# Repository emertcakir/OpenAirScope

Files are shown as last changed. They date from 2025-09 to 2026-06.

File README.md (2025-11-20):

EMC
------
# OpenAirScope 🌍💨

**OpenAirScope** is an open-source hardware and software project designed for advanced environmental monitoring and air quality measurement. It is based on the STM32H743 and ESP32-C3, supports LoRaWAN, and is equipped with a wide range of up-to-date sensors and display options.

### PCB 3D
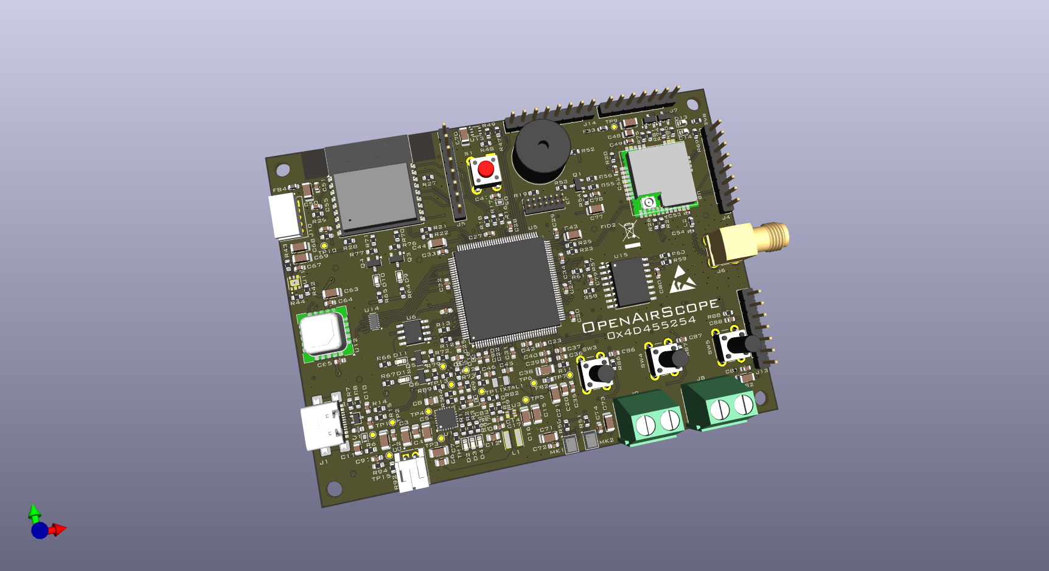
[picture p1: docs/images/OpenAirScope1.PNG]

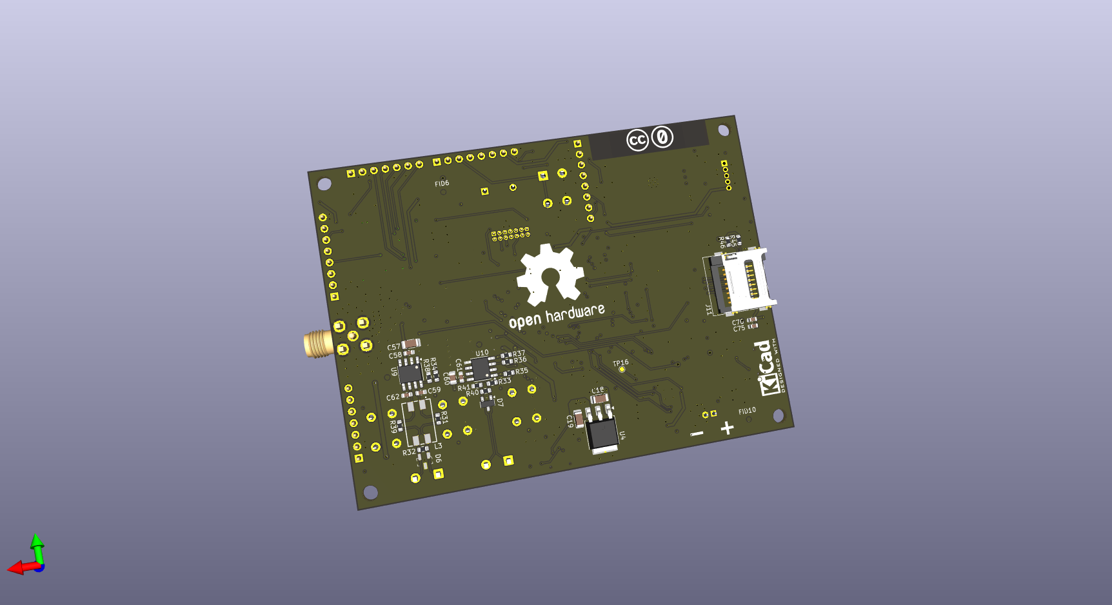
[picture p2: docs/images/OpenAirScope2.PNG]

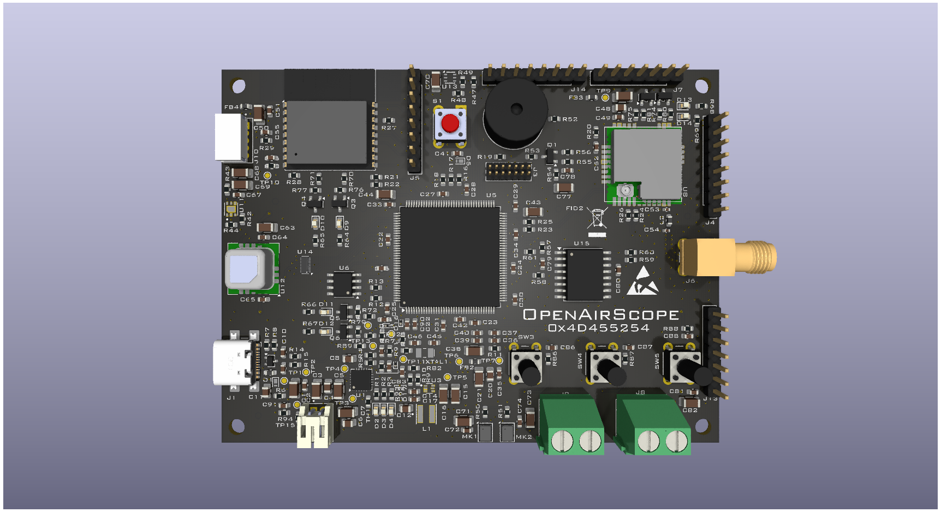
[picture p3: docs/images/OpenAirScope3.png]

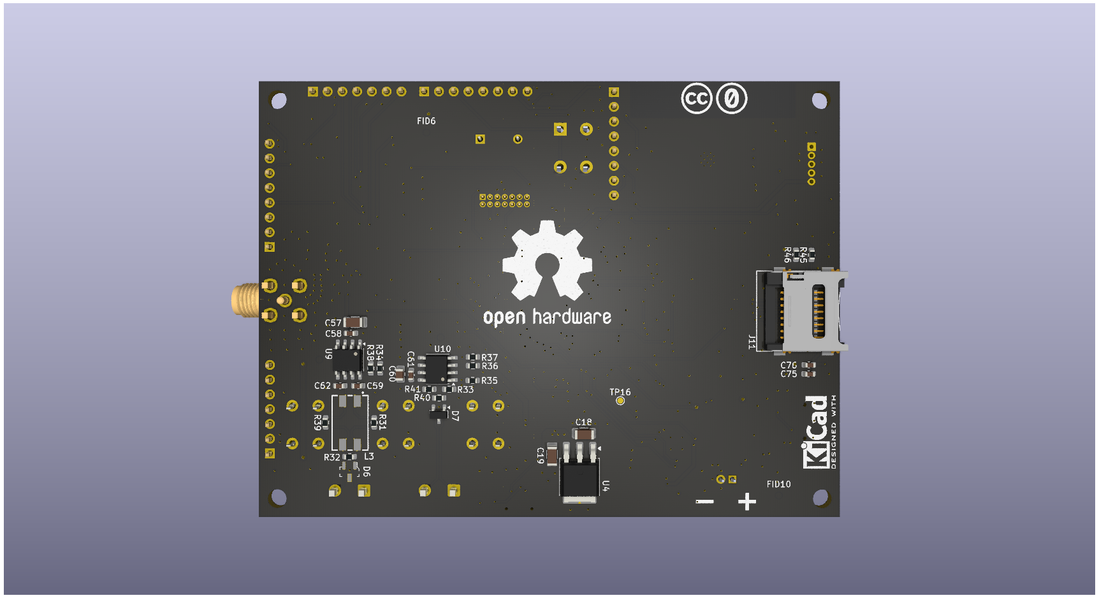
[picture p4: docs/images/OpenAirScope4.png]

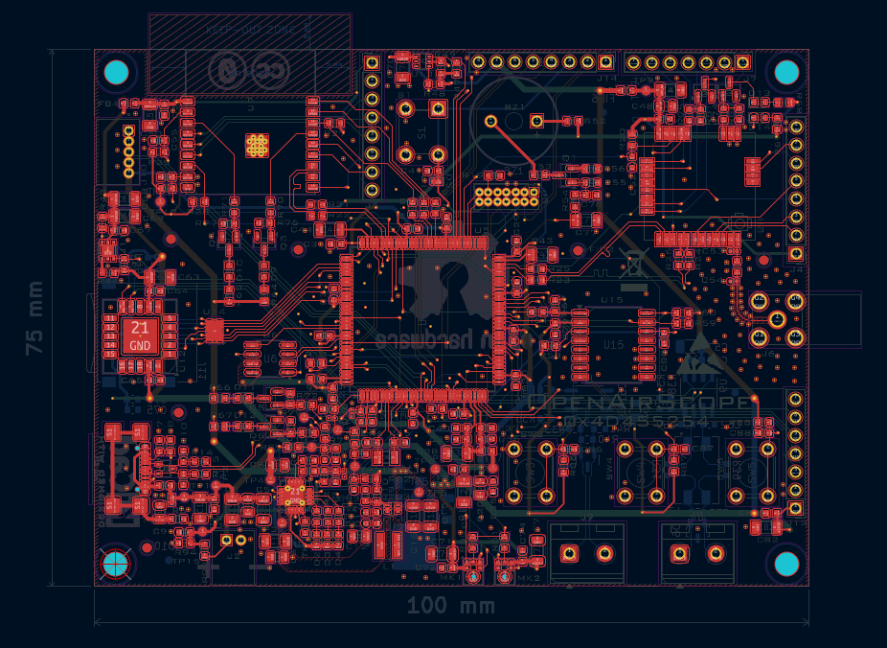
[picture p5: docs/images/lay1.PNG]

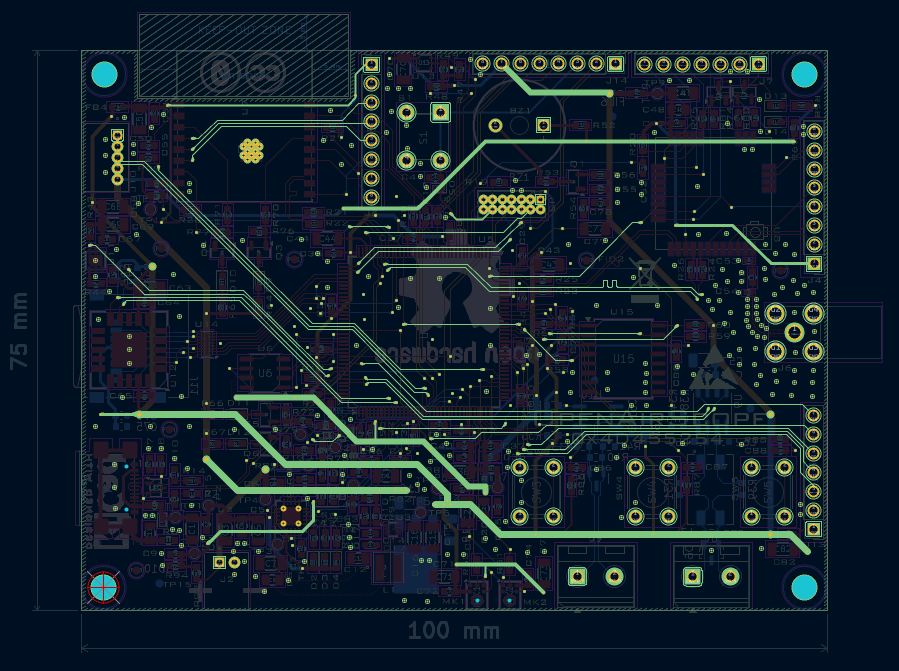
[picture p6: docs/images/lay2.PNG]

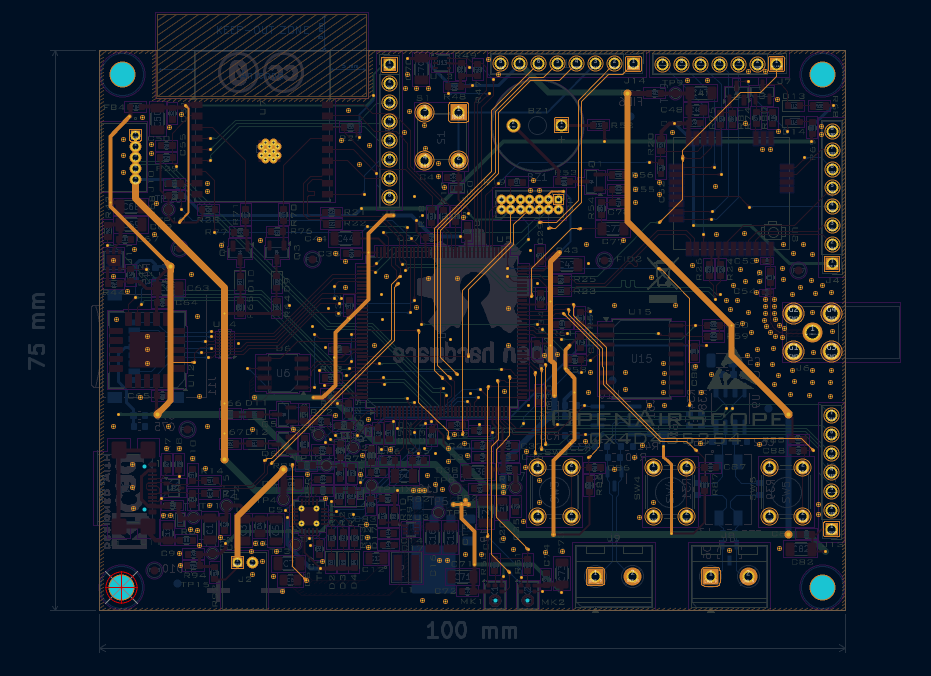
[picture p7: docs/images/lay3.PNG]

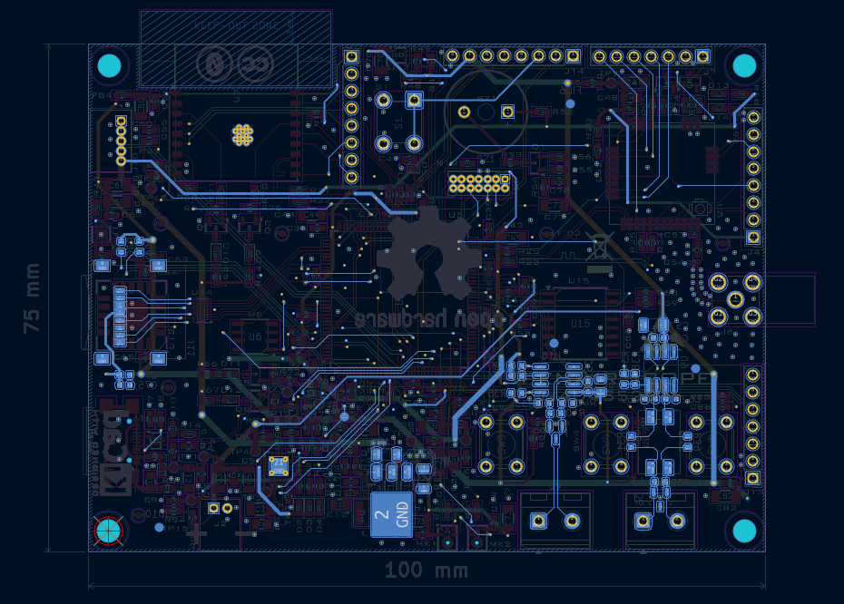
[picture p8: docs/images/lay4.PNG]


## Features

* **High-Performance MCU**:

  * STM32H743 (ARM Cortex-M7, 400 MHz)
  * Capable of running advanced algorithms and real-time data processing
  * Multiple communication interfaces (I²C, SPI, UART, CAN, USB, RS485)

* **Wireless Communication**:

  * **ESP32-C3-WROOM-02** → Wi-Fi + Bluetooth LE
  * **RAK3172 (LoRaWAN)** → Low-power, long-range wireless communication
  * External **SMA antenna connector** (for LoRa)

* **Sensor Support (Optional/Modular)**:

  * **SGP41-D-R4** → Gas sensor (VOC and NOx measurement)
  * **SCD40-D-R2** → CO₂, temperature, and humidity sensor
  * **SPS30** → Particulate matter sensor (PM1.0, PM2.5, PM4, PM10)
  * **LTR-303ALS-01 (Optional)** → Ambient light sensor
  * **SPH0645LM4H-B (2 units)** → Digital MEMS microphone (ambient noise, sound level, acoustic analysis)
  * Expandable design: additional sensors such as pressure or UV can be integrated

* **Display**:

  * **1.5-inch RGB OLED Display Module**
  * 65K RGB colors, 128×128 resolution
  * SPI interface for fast graphics and real-time data visualization

* **Power Management**:

  * **Li-Ion battery support**
  * USB-powered with **simultaneous battery charging**
  * Suitable for both portable and stationary applications

* **Flexible Communication**:

  * USB-C interface
  * RS485 (for industrial environments)
  * CAN-Bus support
  * IoT integration via Wi-Fi and LoRaWAN

* **Modular Design**:

  * Optional sensor add/remove capability
  * External SMA antenna for long-range connectivity
  * Developer-friendly accessible pinout

* **Software**:

  * STM32CubeIDE / PlatformIO support
  * Open-source drivers and example libraries
  * Example algorithms for air quality and environmental data evaluation
  * OLED display example code for real-time visualization of sensor data

## Use Cases

* Smart city solutions
* Industrial environment monitoring
* Indoor/outdoor air quality tracking
* Noise pollution and sound analysis
* Portable IoT devices with OLED display
* Long-range LoRaWAN field applications
* Research and education projects

<a href="https://www.pcbway.com/project/shareproject/OpenAirScope_Open_Source_Environmental_Monitoring_Air_Quality_Node_39ce8042.html">
  PCB from PCBWay
</a>

## Contributing

This project is open source. Contributions are welcome for new sensor support, software development, or documentation improvements. You can submit pull requests or open issues.

## License

Released under the MIT License.

CRITICAL WARNING: This PCB design is currently an experimental, unverified prototype (AS-IS). I have not yet manufactured or functionally tested this version. Proceeding with production carries a high risk of failure and is undertaken solely at your own risk.
---

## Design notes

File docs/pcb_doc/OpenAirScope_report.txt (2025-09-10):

PCB statistics report
=====================
- Date: Mon Sep  8 09:43:07 2025
- Project: OpenAirScope
- Board name: OpenAirScope

Board
-----
- Width: 100.0000 mm
- Height: 75.0000 mm
- Area: 7367.3152 mm²

Pads
----
- Through hole: 102
- SMD: 849
- Connector: 0
- NPTH: 8

Vias
----
- Through vias: 473
- Blind/buried: 0
- Micro vias: 0

Components
----------

| | Front Side | Back Side | Total |
|---|---|---|---|
|THT: | 16 | 0 | 16 |
|SMD: | 207 | 34 | 241 |
|Unspecified:  | 20 | 5 | 25 |
|Total: | 243 | 39 | 282 |

Drill holes
-----------

| Count | Shape | X Size | Y Size | Plated | Via/Pad | Start Layer | Stop Layer |
|---|---|---|---|---|---|---|---|
| 249 | Round | 0.3000 mm | 0.3000 mm | PTH | Via | F.Cu | B.Cu |
| 217 | Round | 0.2500 mm | 0.2500 mm | PTH | Via | F.Cu | B.Cu |
| 40 | Round | 1.0000 mm | 1.0000 mm | PTH | Pad | F.Cu | B.Cu |
| 16 | Round | 1.1000 mm | 1.1000 mm | PTH | Pad | F.Cu | B.Cu |
| 16 | Round | 0.2000 mm | 0.2000 mm | PTH | Pad | F.Cu | B.Cu |
| 14 | Round | 0.6500 mm | 0.6500 mm | PTH | Pad | F.Cu | B.Cu |
| 7 | Round | 0.5000 mm | 0.5000 mm | PTH | Via | F.Cu | B.Cu |
| 5 | Round | 0.7300 mm | 0.7300 mm | PTH | Pad | F.Cu | B.Cu |
| 4 | Round | 3.2000 mm | 3.2000 mm | NPTH | Pad | F.Cu | B.Cu |
| 4 | Round | 1.6500 mm | 1.6500 mm | PTH | Pad | F.Cu | B.Cu |
| 4 | Round | 1.2000 mm | 1.2000 mm | PTH | Pad | F.Cu | B.Cu |
| 2 | Round | 0.8000 mm | 0.8000 mm | PTH | Pad | F.Cu | B.Cu |
| 2 | Round | 0.6500 mm | 0.6500 mm | NPTH | Pad | F.Cu | B.Cu |
| 2 | Round | 0.5000 mm | 0.5000 mm | NPTH | Pad | N/A | N/A |
| 1 | Round | 1.5500 mm | 1.5500 mm | PTH | Pad | F.Cu | B.Cu |

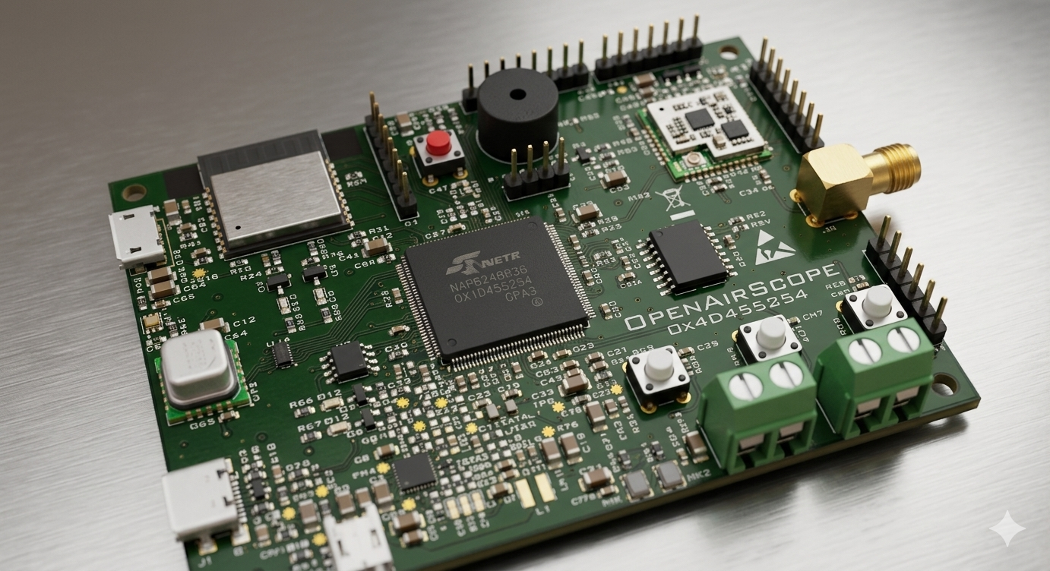
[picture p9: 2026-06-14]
docs/images/Render.png

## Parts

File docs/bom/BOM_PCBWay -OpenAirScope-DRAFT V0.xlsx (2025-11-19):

 |  |  | OpenAirScope
Item # | *Designator | *Qty | Manufacturer | *Mfg Part # | Description / Value | *Package/Footprint | Type | Your Instructions / Notes
1 | C53,C54 | 2 |  |  | DNP | C_0402_1005Metric
2 | SW3,SW4,SW5 | 3 |  | TC-1102-C-S-B |  | SW_PUSH_6mm_H13mm
3 | R60,R74,R52,R88,R75,R70,R57,R86,R71,R58,R73,R87,R59,R72 | 14 |  | ERJ-3EKF4701V | 4.7k | R_0603_1608Metric
4 | C15,C18 | 2 |  | CL31A226MOCLNNC | 22uF | C_1206_3216Metric
5 | C78,C27,C39,C55,C26,C86,C33,C30,C81,C34,C64,C14,C32,C36,C41,C88,C35,C80,C31,C17,C28,C49,C65,C23,C2,C29,C22,C25,C67,C42,C51,C24,C87,C52,C79,C76,C58,C61 | 38 |  | CC0603KRX7R8BB104 | 100nF | C_0603_1608Metric
6 | C40,C92,C84,C37,C90 | 5 |  | CC0603KRX7R8BB102 | 1nF | C_0603_1608Metric
7 | R82,R84,R94,R92,R91,R89 | 6 |  | RC0603FR-0722KL | 22K | R_0603_1608Metric
8 | C69,C71,C70,C73,C77,C50,C68,C7,C21,C63,C38,C82,C5,C1 | 14 |  | CGA5L2X7R1E105K160AA | 1uF | C_1206_3216Metric
9 | R20,R42,R29,R30,R28,R12,R55,R47,R48,R27,R49,R13,R43,R46,R37,R36,R33,R41,R45,R35 | 20 |  | RC0603FR-0710KL | 10K | R_0603_1608Metric
10 | TH1 | 1 |  | ERT-J1VR103J | THERMISTOR NTC 10KOHM 4250K 0603 | R_0603_1608Metric
11 | C4,C12,C20,C6,C8,C48,C60 | 7 |  | GRM21BC71E475KE11L | 4.7UF | C_0805_2012Metric
12 | R19,R6 | 2 |  | ERJ-3EKF1000V | 100R | R_0603_1608Metric
13 | D17,D16,D15 | 3 |  | ESD9B3.3ST5G |  | D_SOD-923
14 | R22,R90,R93,R17,R53,R23,R61,R26,R83,R21,R15,R11,R14,R16,R18,R56,R25,R24,R39,R38,R31,R34 | 22 |  | RC0603JR-070RL | 0R | R_0603_1608Metric
15 | D14,D13,D11,D2,D3,D10,D12,D4,D9 | 9 |  | 150060RS75000 |  | LED_0603_1608Metric
16 | U3 | 1 |  | TPS61023DRLT | TPS61023DRLT | SOT50P160X60-6N
17 | U7 | 1 |  | ESP32-C3-WROOM-02-N4 | ESP32-C3-WROOM-02-N4 | ESP32-C3-WROOM-02-N4
18 | J13,J7 | 2 |  | PZ254V-11-07P | PinHeader_1x07_P2.54mm_Vertical | Conn_01x07_Pin;Conn_01x07_Pin
19 | D1,D5 | 2 |  | PTVS5V0Z1USKYL |  | Nexperia_DSN1608-2_1.6x0.8mm
20 | U5 | 1 |  | STM32H743ZIT6 |  | LQFP-144_20x20mm_P0.5mm
21 | R80,R78,R77,R81,R79,R76 | 6 |  | RC0603FR-0747KL | 47K | R_0603_1608Metric
22 | Q8,Q7,Q5,Q3,Q6,Q1,Q4 | 7 |  | BC817 |  | SOT-23
23 | U13 | 1 |  | LTR-303ALS-01 |  | Lite-On_LTR-303ALS-01
24 | C9,C10 | 2 |  | 0603YC470KAT2A | 47PF | C_0603_1608Metric
25 | J6 | 1 |  | RFPC-SMA27-F |  | GRADCONN_RFPC-SMA27-F
26 | R10 | 1 |  | ERJ-3EKF1003V | 100K | R_0603_1608Metric
27 | J14,J5,J4 | 3 |  | X6511WV-08H-C60D30 | Conn_01x08_Pin;Conn_01x08_Pin | PinHeader_1x08_P2.54mm_Vertica
28 | U8 | 1 |  | RAK3172-8-SM-NI | RAK3172 | 32-SMD Module
29 | C46,C45 | 2 |  | 06035A100K4T4A | 10PF | C_0603_1608Metric
30 | R54,R69,R66,R3,R64,R68,R2,R1,R4,R67,R65 | 11 |  | ERA-3AEB102V | 1K | R_0603_1608Metric
31 | J8,J9 | 2 |  | RND 205-00045 |  | TerminalBlock_RND_205-00045_1x02_P5.00mm_Horizontal
32 | U14 | 1 |  | EMIF06-MSD02N16 | OnSemi_UDFN-16-1EP_1.35x3.3mm_P0.4mm_EP0.4x2.8mm
33 | U15 | 1 |  | DS3231M+TRL |  | SOIC-16W_7.5x10.3mm_P1.27mm
34 | U11 | 1 |  | SGP41-D-R4 |  | XDCR_SGP41-D-R4
35 | L1 | 1 |  | XEL4030-102MEC |  | IND_XEL4030-102MEC
36 | C83,C91,C89 | 3 |  | C0603X223K5RECAUTO | 22NF | C_0603_1608Metric
37 | U6 | 1 |  | M95256-WMN6P |  | SOIC-8_3.9x4.9mm_P1.27mm
38 | BZ1 | 1 |  | ABT-410-RC | MagneticBuzzer_ProSignal_ABT-410-RC
39 | FB1,FB2,FB3,FB4 | 4 |  | BLM18AG601BH1D |  | L_0603_1608Metric
40 | J2 | 1 |  | S2B-PH-K-S | JST_S2B-PH-K-S_LF__SN_
41 | C72,C74 | 2 |  | CC0603KRX7R9BB201 | 200pF | C_0603_1608Metric
42 | C47,C3,C16,C57,C19 | 5 |  | CL31B106KAHNNNE | 10UF | C_1206_3216Metric
43 | J1 | 1 |  | USB4110-GF-A | USB_C_Receptacle_GCT_USB4110
44 | MK2,MK1 | 2 |  | SPH0645LM4H-B | Knowles_SPH0645LM4H-6_3.5x2.65mm
45 | U1 | 1 |  | MCP73871-2CAI/ML | QFN-20-1EP_4x4mm_P0.5mm_EP2.5x2.5mm_ThermalVias
46 | U2 | 1 |  | TPD2E2U06DCKR |  | SOT-323_SC-70
47 | R8,R7 | 2 |  | RC0603FR-075K1L | 5.1K | R_0603_1608Metric
48 | C11 | 1 |  | CC0805KRX7R9BB222 | 2.2NF | C_0805_2012Metric
49 | J3 | 1 |  | STDC14 | PinHeader_2x07_P1.27mm_Vertical
50 | R51,R50 | 2 |  | RC0603JR-0751RL | 51R | R_0603_1608Metric
51 | XTAL1 | 1 |  | ECS-.327-12.5-34B-TR |  | SMD-2_3.2x1.5mm
52 | J10 | 1 |  | S5B-ZR | JST_S5B-ZR_LF__SN_ | JST_S5B-ZR_LF__SN_
53 | S1 | 1 |  | 1825910-6 | Switch_Tactile_THT_6x6mm
54 | R9 | 1 |  | RC0603FR-07732KL | 732k | R_0603_1608Metric
55 | C43,C44 | 2 |  | C1206C225M3RECAUTO | 2.2UF | C_1206_3216Metric
56 | U12 | 1 |  | SCD40-D-R2 | Sensirion_SCD4x-1EP_10.1x10.1mm_P1.25mm_EP4.8x4.8mm
57 | R44 | 1 |  | RC0603FR-134R7L | 4.7K | R_0603_1608Metric
58 | L2 | 1 |  | RC0603JR-070RL |  | L_0603_1608Metric
59 | R5 | 1 |  | RN73A1J5K0FTD | 5K | R_0603_1608Metric
60 | C75 | 1 |  | GXT188R61C106KE13D | 10UF | C_0603_1608Metric
61 | R40,R32 | 2 |  | ERA-3AEB121V | 120R | R_0603_1608Metric
62 | D6 | 1 |  | PESD1CAN_215 |  | SOT-23-3
63 | U10 | 1 |  | MAX3485 |  | SOIC-8_3.9x4.9mm_P1.27mm
64 | U9 | 1 |  | SN65HVD230 |  | SOIC-8_3.9x4.9mm_P1.27mm
65 | D7 | 1 |  | SM712-02HTG |  | SOT-23
66 | L3 | 1 |  | XEL4030-102MEC | WE-SL2
67 | U4 | 1 |  | LD39150DT33-R |  | TO-252-3_TabPin2
68 | C59,C62 | 2 |  | 06033C101MAT2A | 100NF | C_0603_1608Metric
69 | J11 | 1 |  | 693072010801 | microSD_HC_Wuerth_693072010801

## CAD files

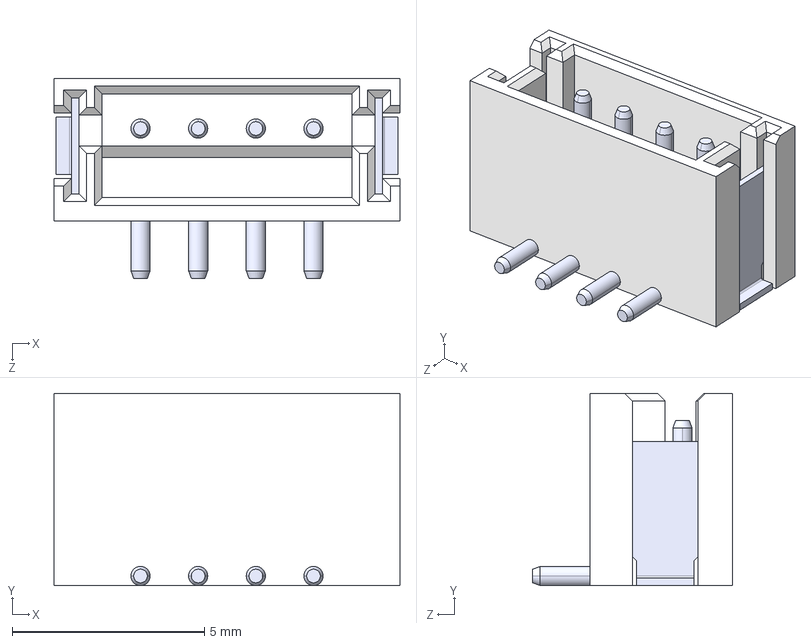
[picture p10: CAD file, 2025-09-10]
hardware/3D/B4B-ZR-SM4-TF--3DModel-STEP-56544.STEP
9.00 x 5.00 x 5.20 mm
BxB-ZR-SM4_4
BxB-ZR-SM4 pins_4

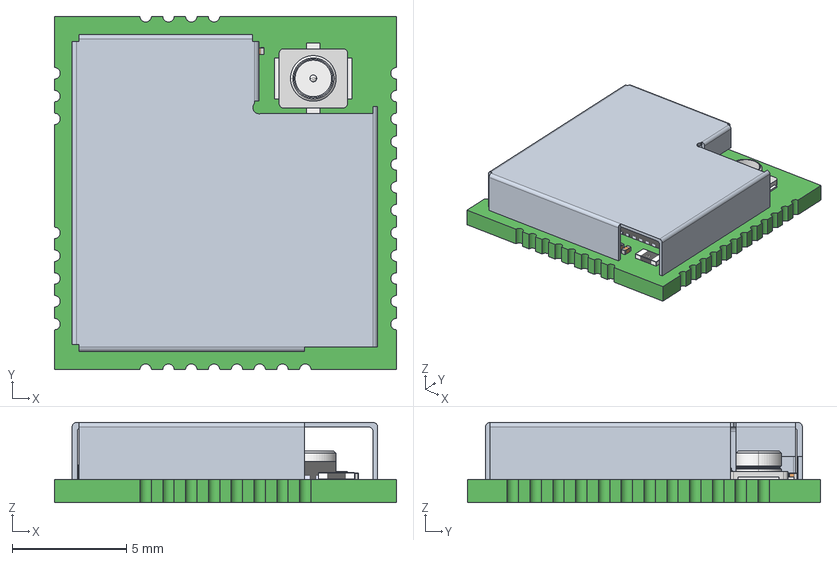
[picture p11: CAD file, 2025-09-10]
hardware/3D/RAK3172--3DModel-STEP-100311.STEP
15.0 x 15.5 x 3.51 mm
0201_SMD_Capacitor x 36
Extruded
R0201 x 7
RES_1005-0402 x 3
QFN48_7x7
NT2016SA
C0402 x 4
crystal_rtf2012
D030A-そ敖裔

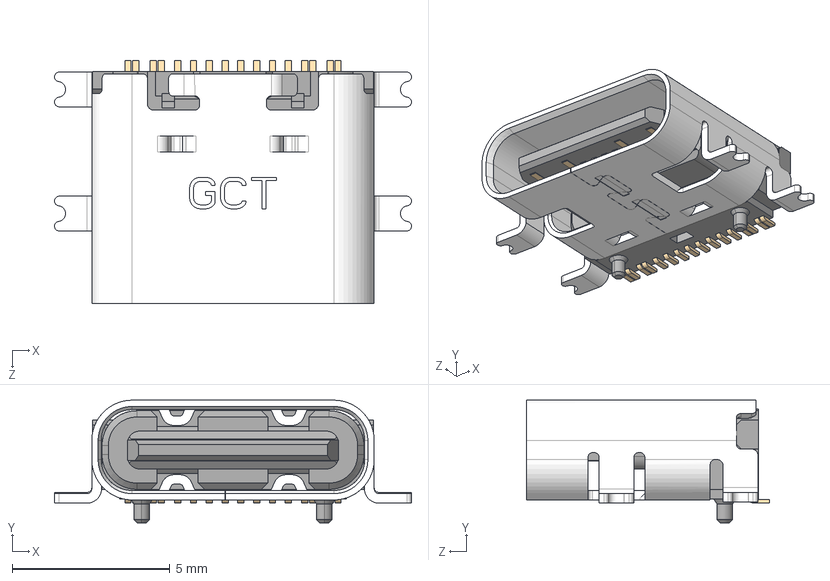
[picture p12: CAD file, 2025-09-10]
hardware/3D/USB4110GFA--3DModel-STEP-269445.STEP
11.3 x 3.89 x 7.70 mm

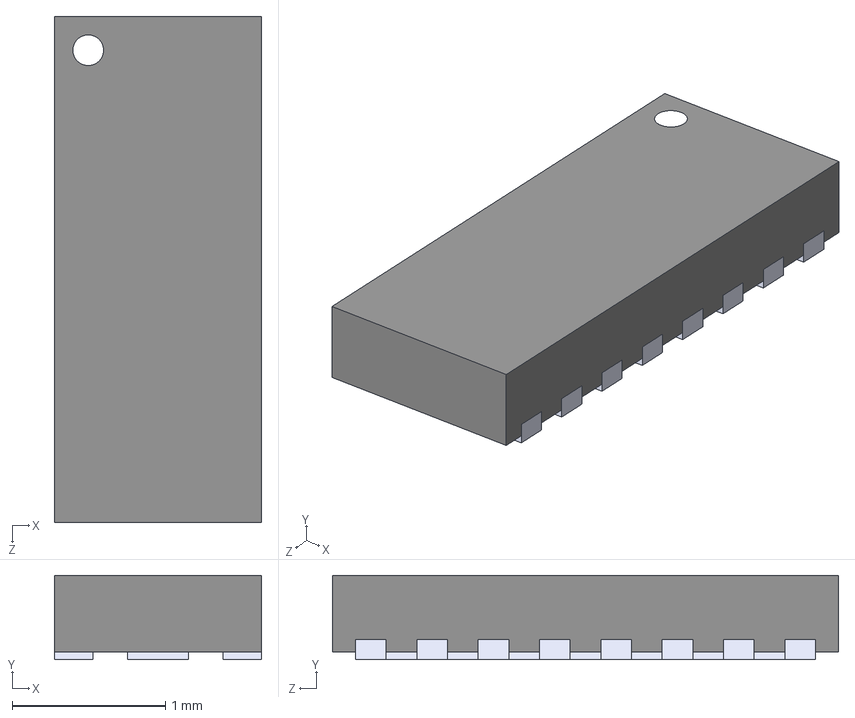
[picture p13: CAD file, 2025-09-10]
hardware/3D/CM1624-08DE.STEP
1.35 x 0.55 x 3.30 mm

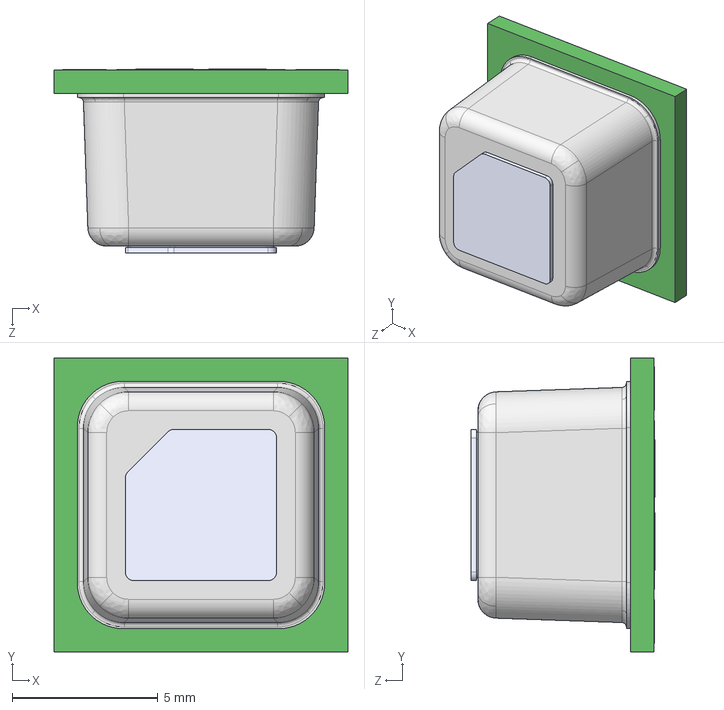
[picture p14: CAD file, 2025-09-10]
hardware/3D/SCD40-D-R2--3DModel-STEP-369182.STEP
10.1 x 10.1 x 6.31 mm

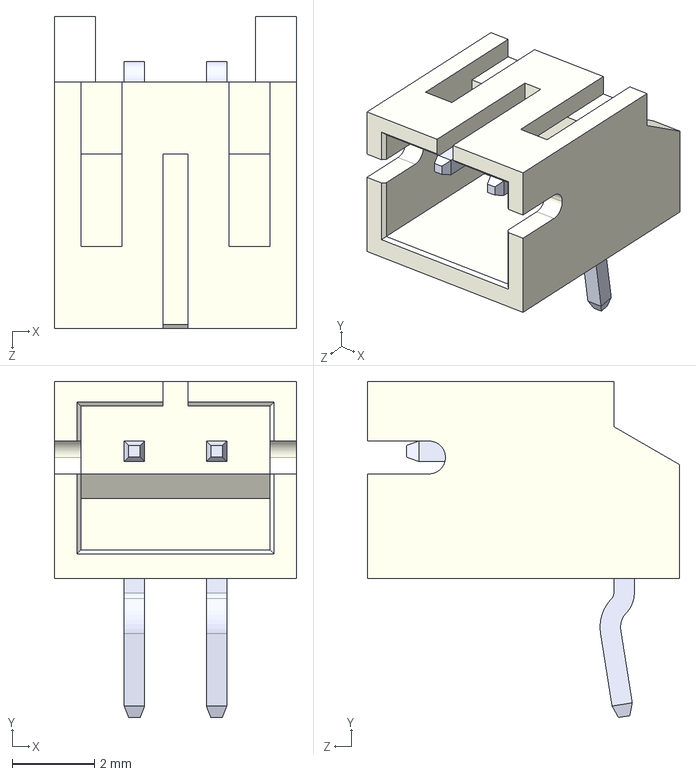
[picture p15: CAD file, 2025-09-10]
hardware/3D/S2B-PH-K-S(LF)(SN)--3DModel-STEP-1.STEP
5.90 x 8.18 x 7.60 mm

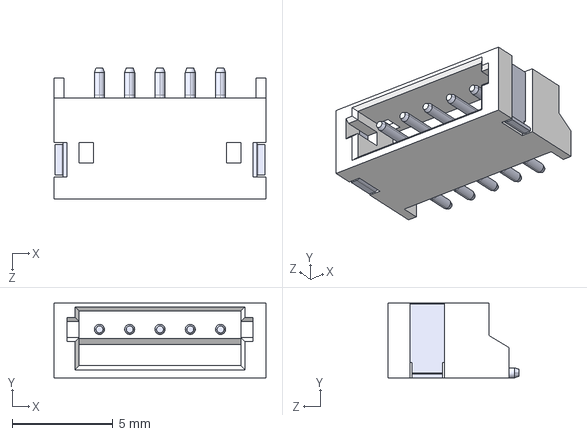
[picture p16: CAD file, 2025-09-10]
hardware/3D/S5B-ZR-SM4A-TF -LF--SN---3DModel-STEP-56544.STEP
10.5 x 3.70 x 6.50 mm

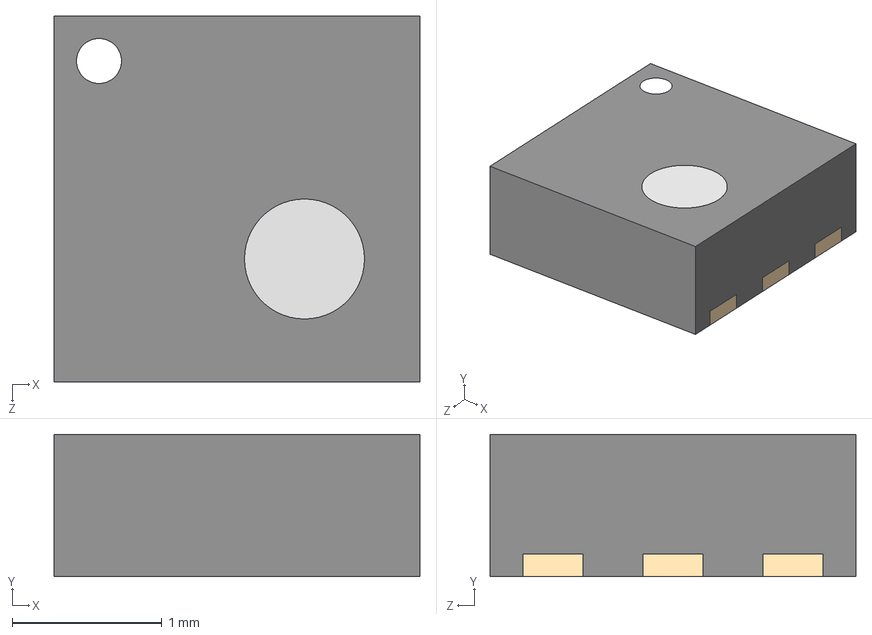
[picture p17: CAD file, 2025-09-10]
hardware/3D/SGP41-D-R4--3DModel-STEP-56544.STEP
2.44 x 0.95 x 2.44 mm

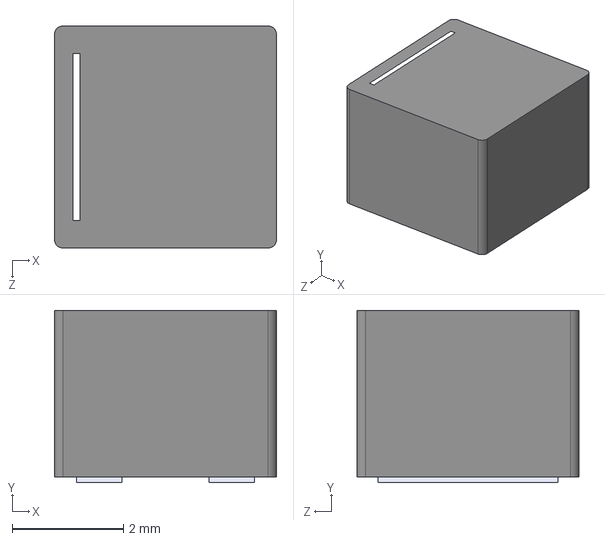
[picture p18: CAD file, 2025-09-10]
hardware/3D/XEL4030-102MEC--3DModel-STEP-269445.STEP
4.00 x 3.10 x 4.00 mm

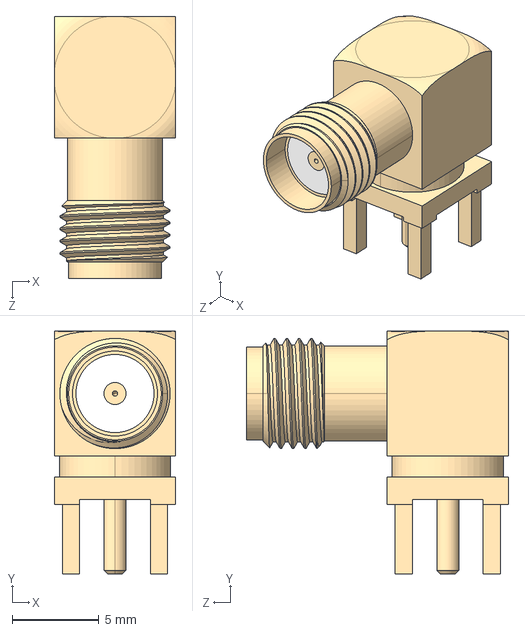
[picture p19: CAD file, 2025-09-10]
hardware/3D/RFPC-SMA27-F--3DModel-STEP-269445.STEP
7.00 x 14.0 x 15.1 mm

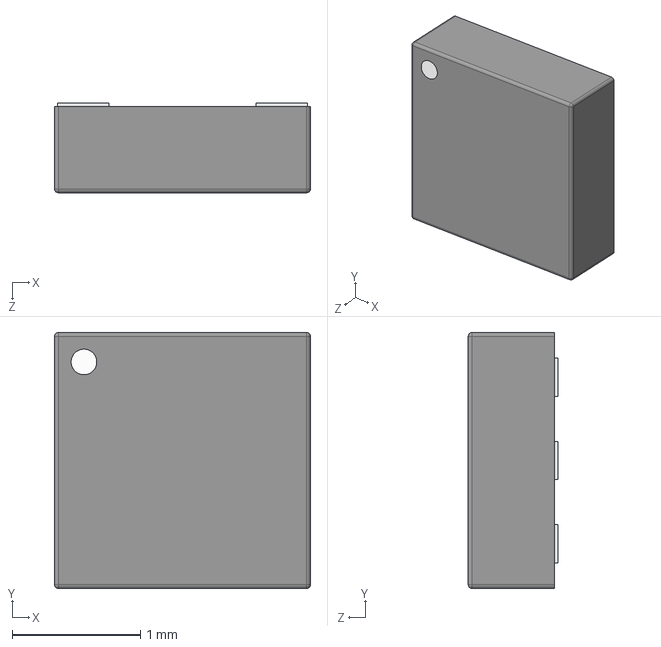
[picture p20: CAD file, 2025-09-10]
hardware/3D/LTR-303ALS-01.stp
2.00 x 2.00 x 0.7 mm

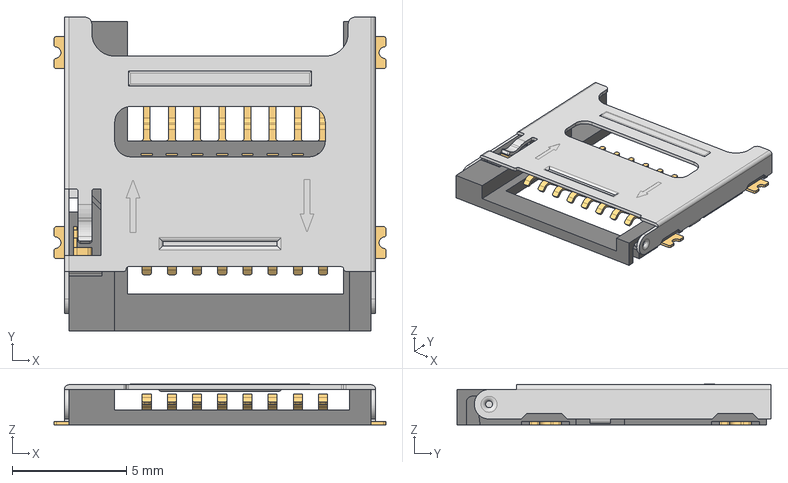
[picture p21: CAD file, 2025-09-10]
hardware/3D/693072010801+%28rev1%29.stp
14.5 x 13.7 x 1.77 mm
693072010801_PIN x 8
693072010801_PATTE x 3
693072010801_CACHE
693072010801_PATTE_SPE

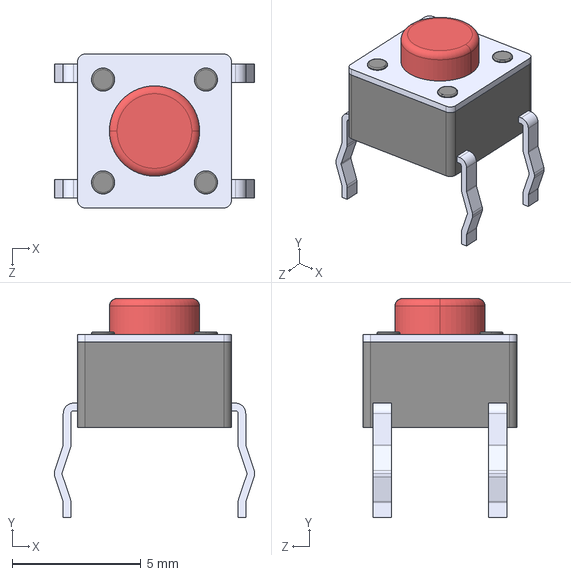
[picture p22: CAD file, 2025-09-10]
hardware/3D/1825910-6--3DModel-STEP-418109.STEP
7.80 x 8.52 x 5.99 mm

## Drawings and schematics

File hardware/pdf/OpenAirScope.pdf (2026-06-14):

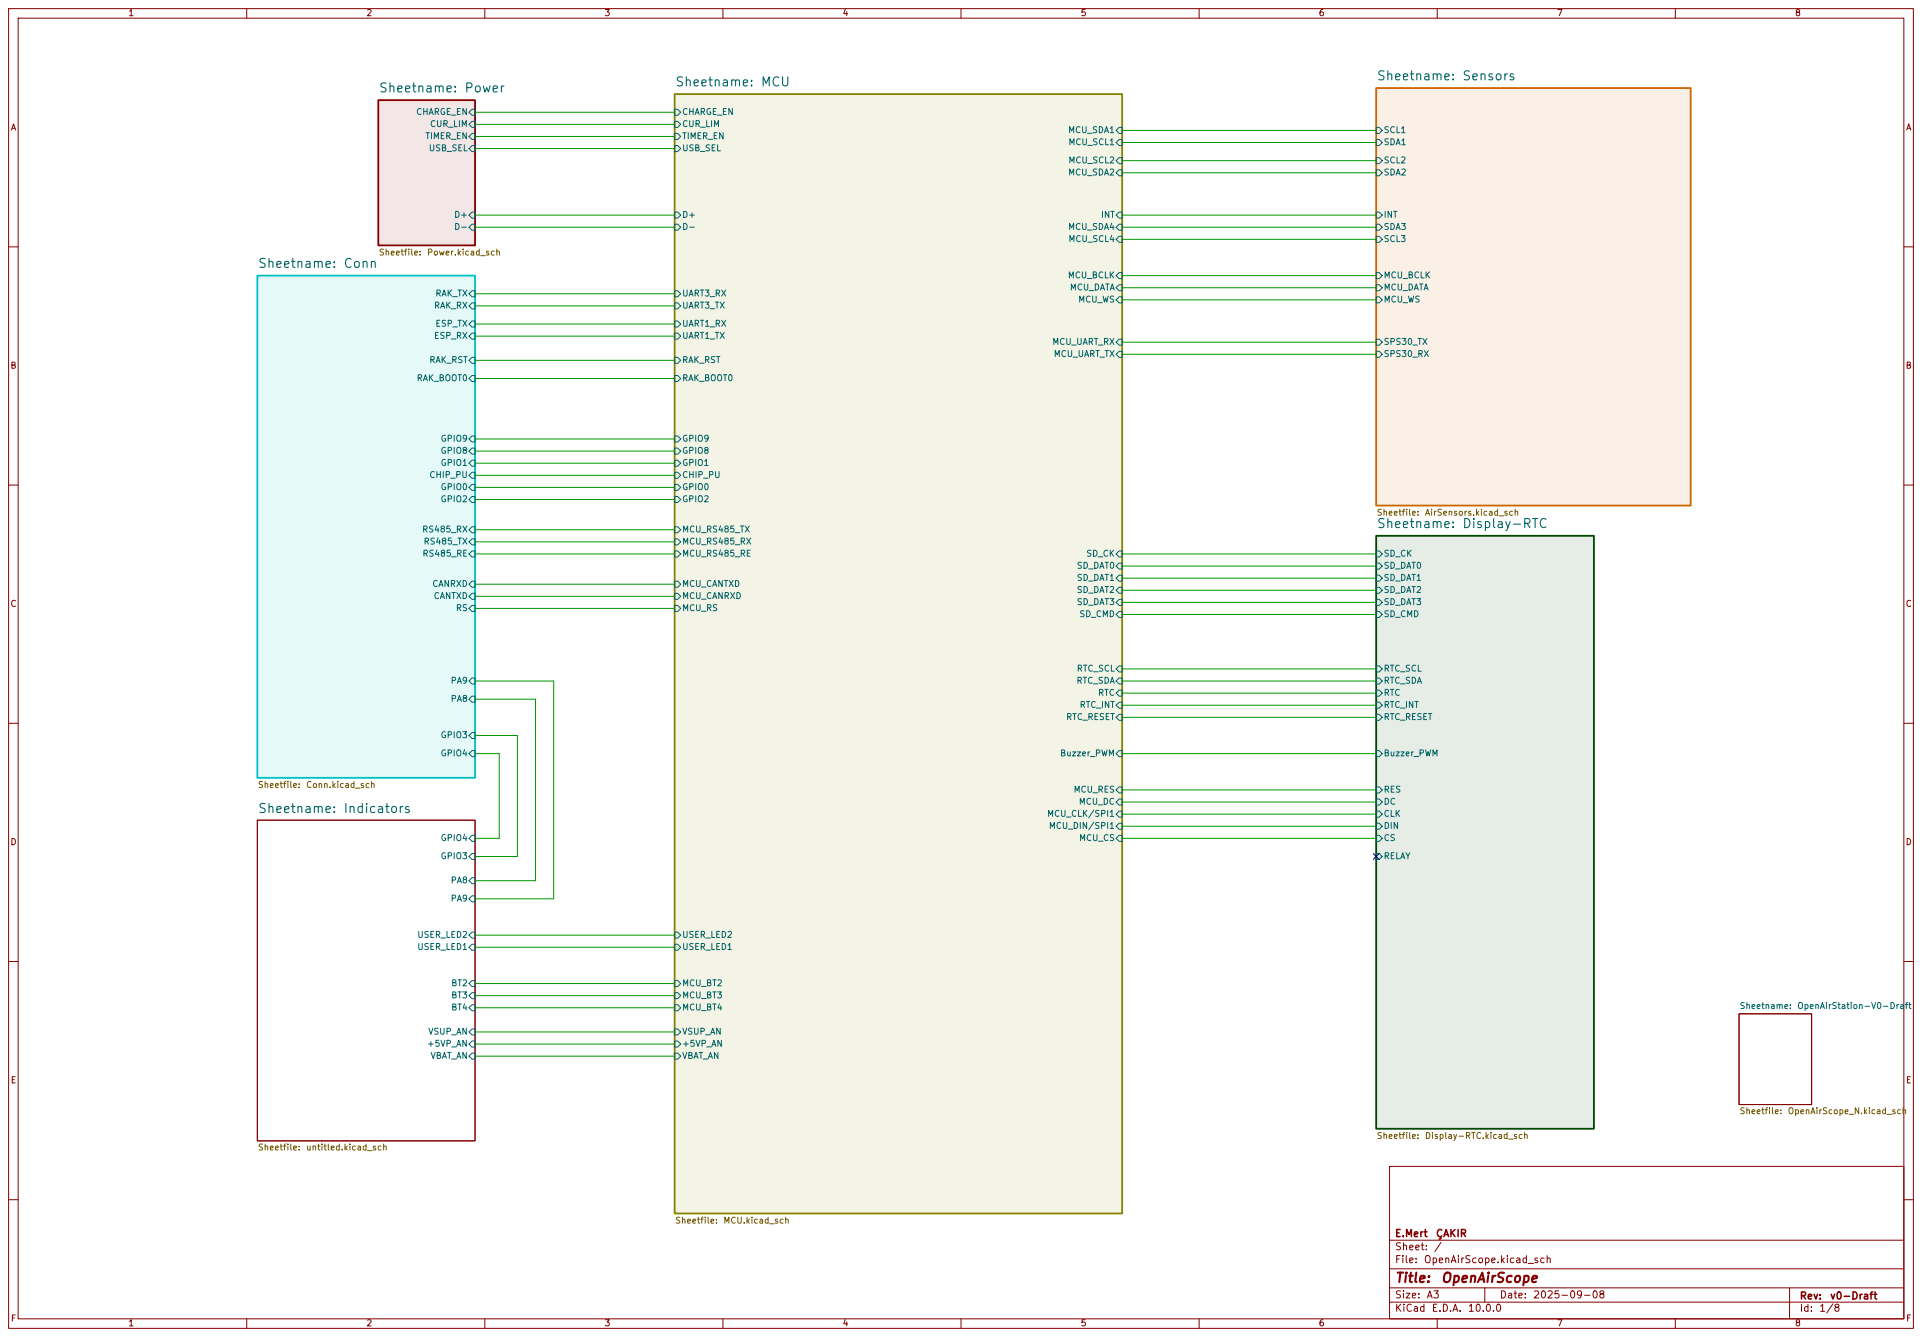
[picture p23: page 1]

Size: A3 | Rev: v0-Draft

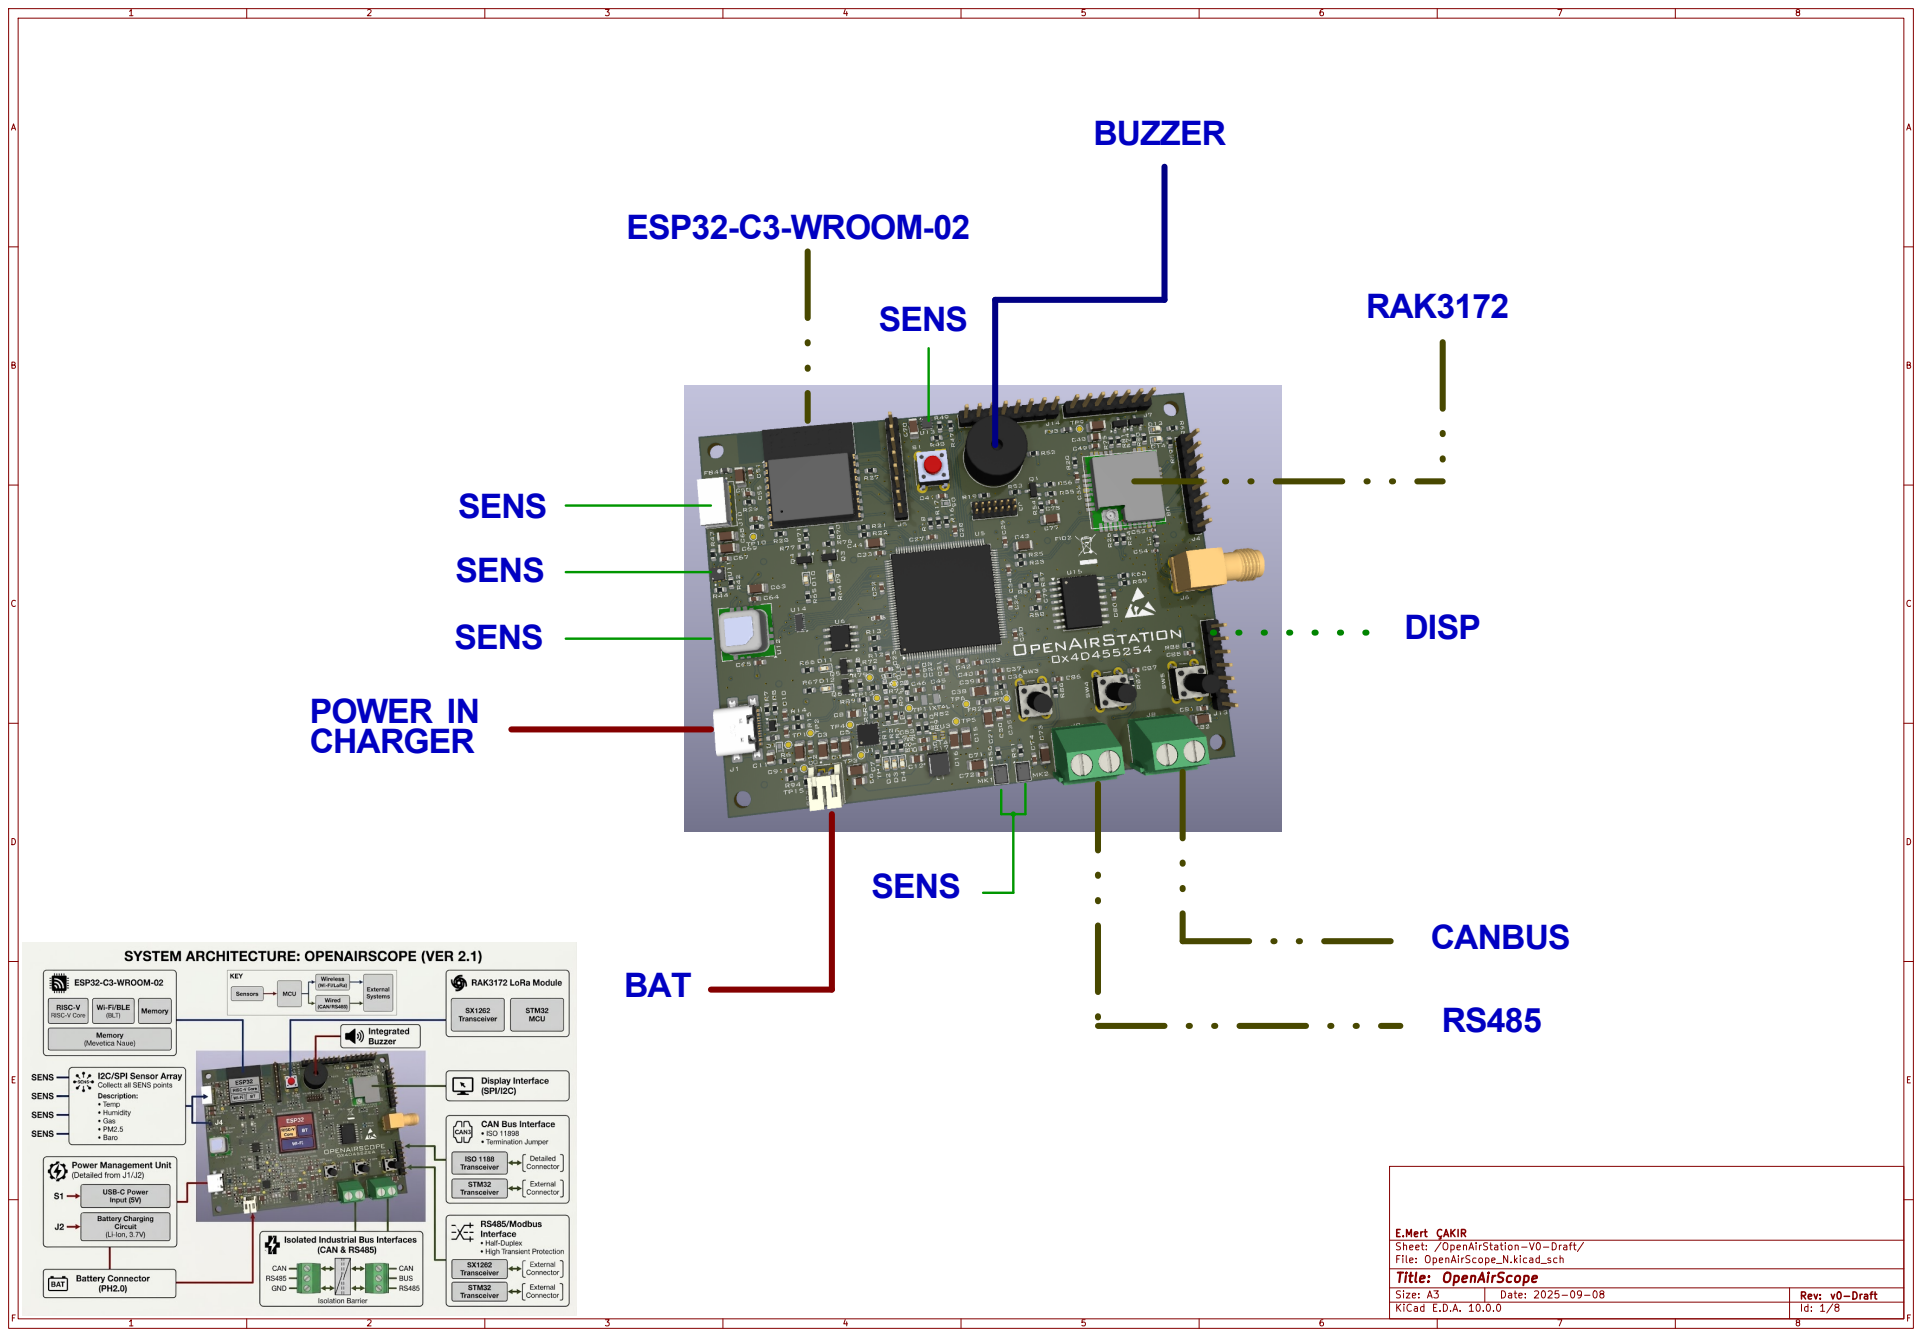
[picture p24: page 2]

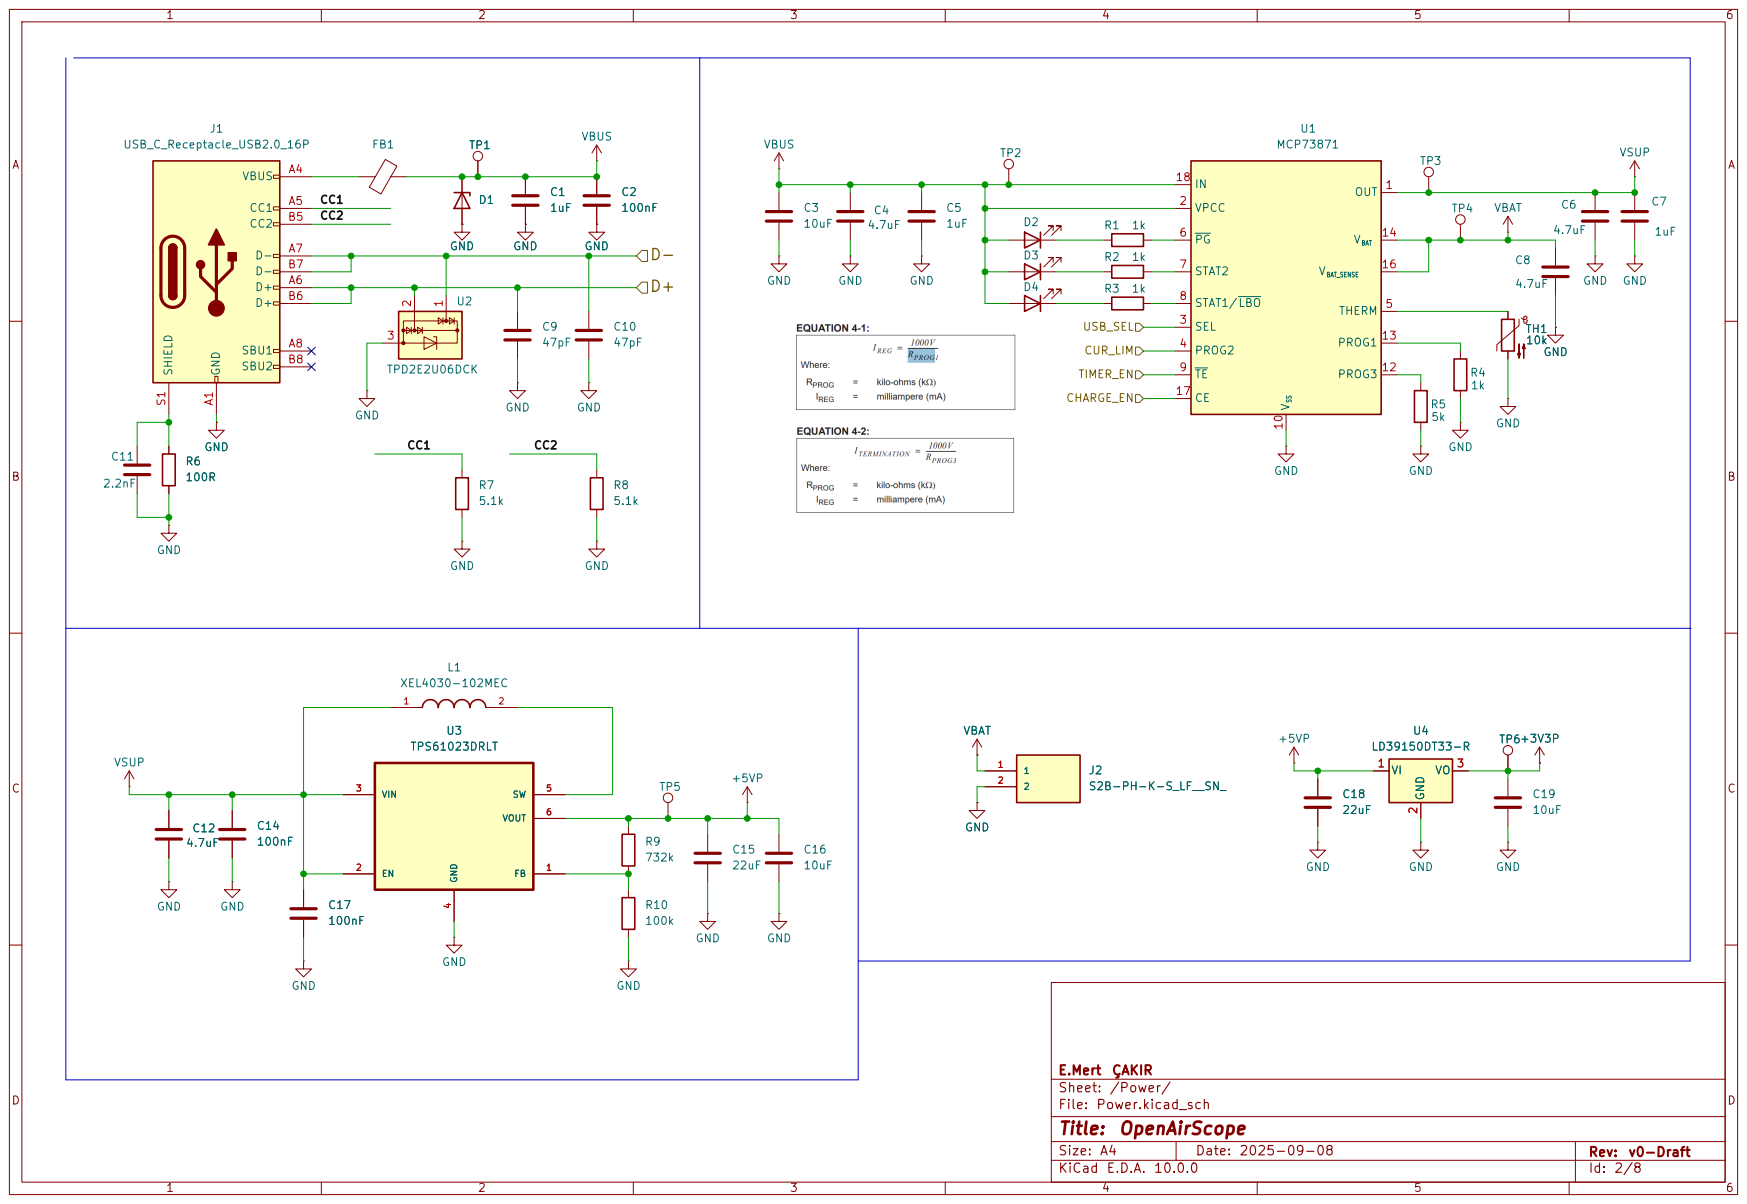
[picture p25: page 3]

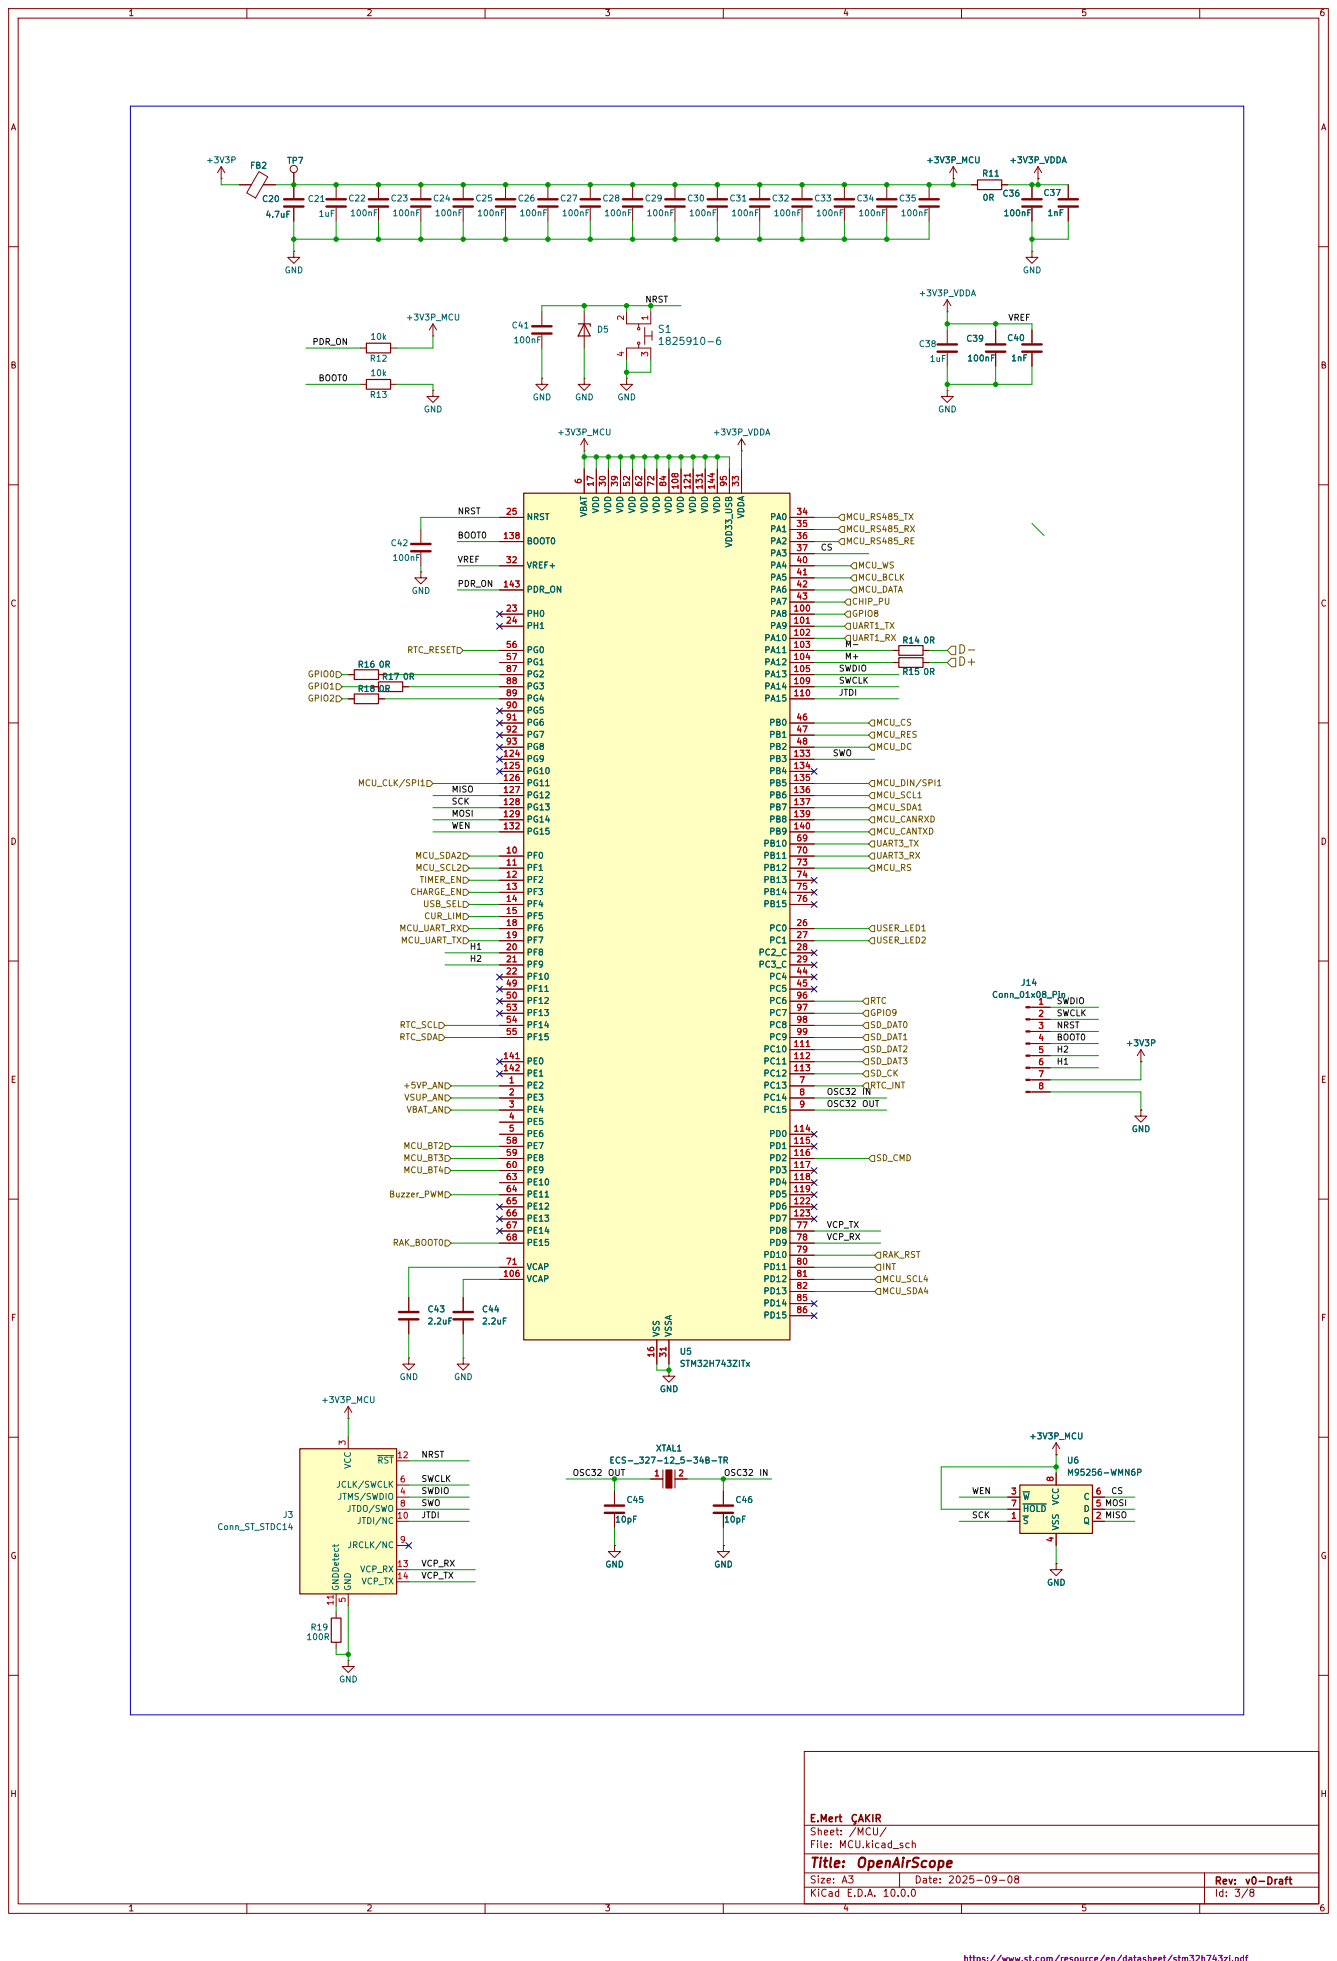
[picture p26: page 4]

https://www.st.com/resource/en/datasheet/stm32h743zi.pdf

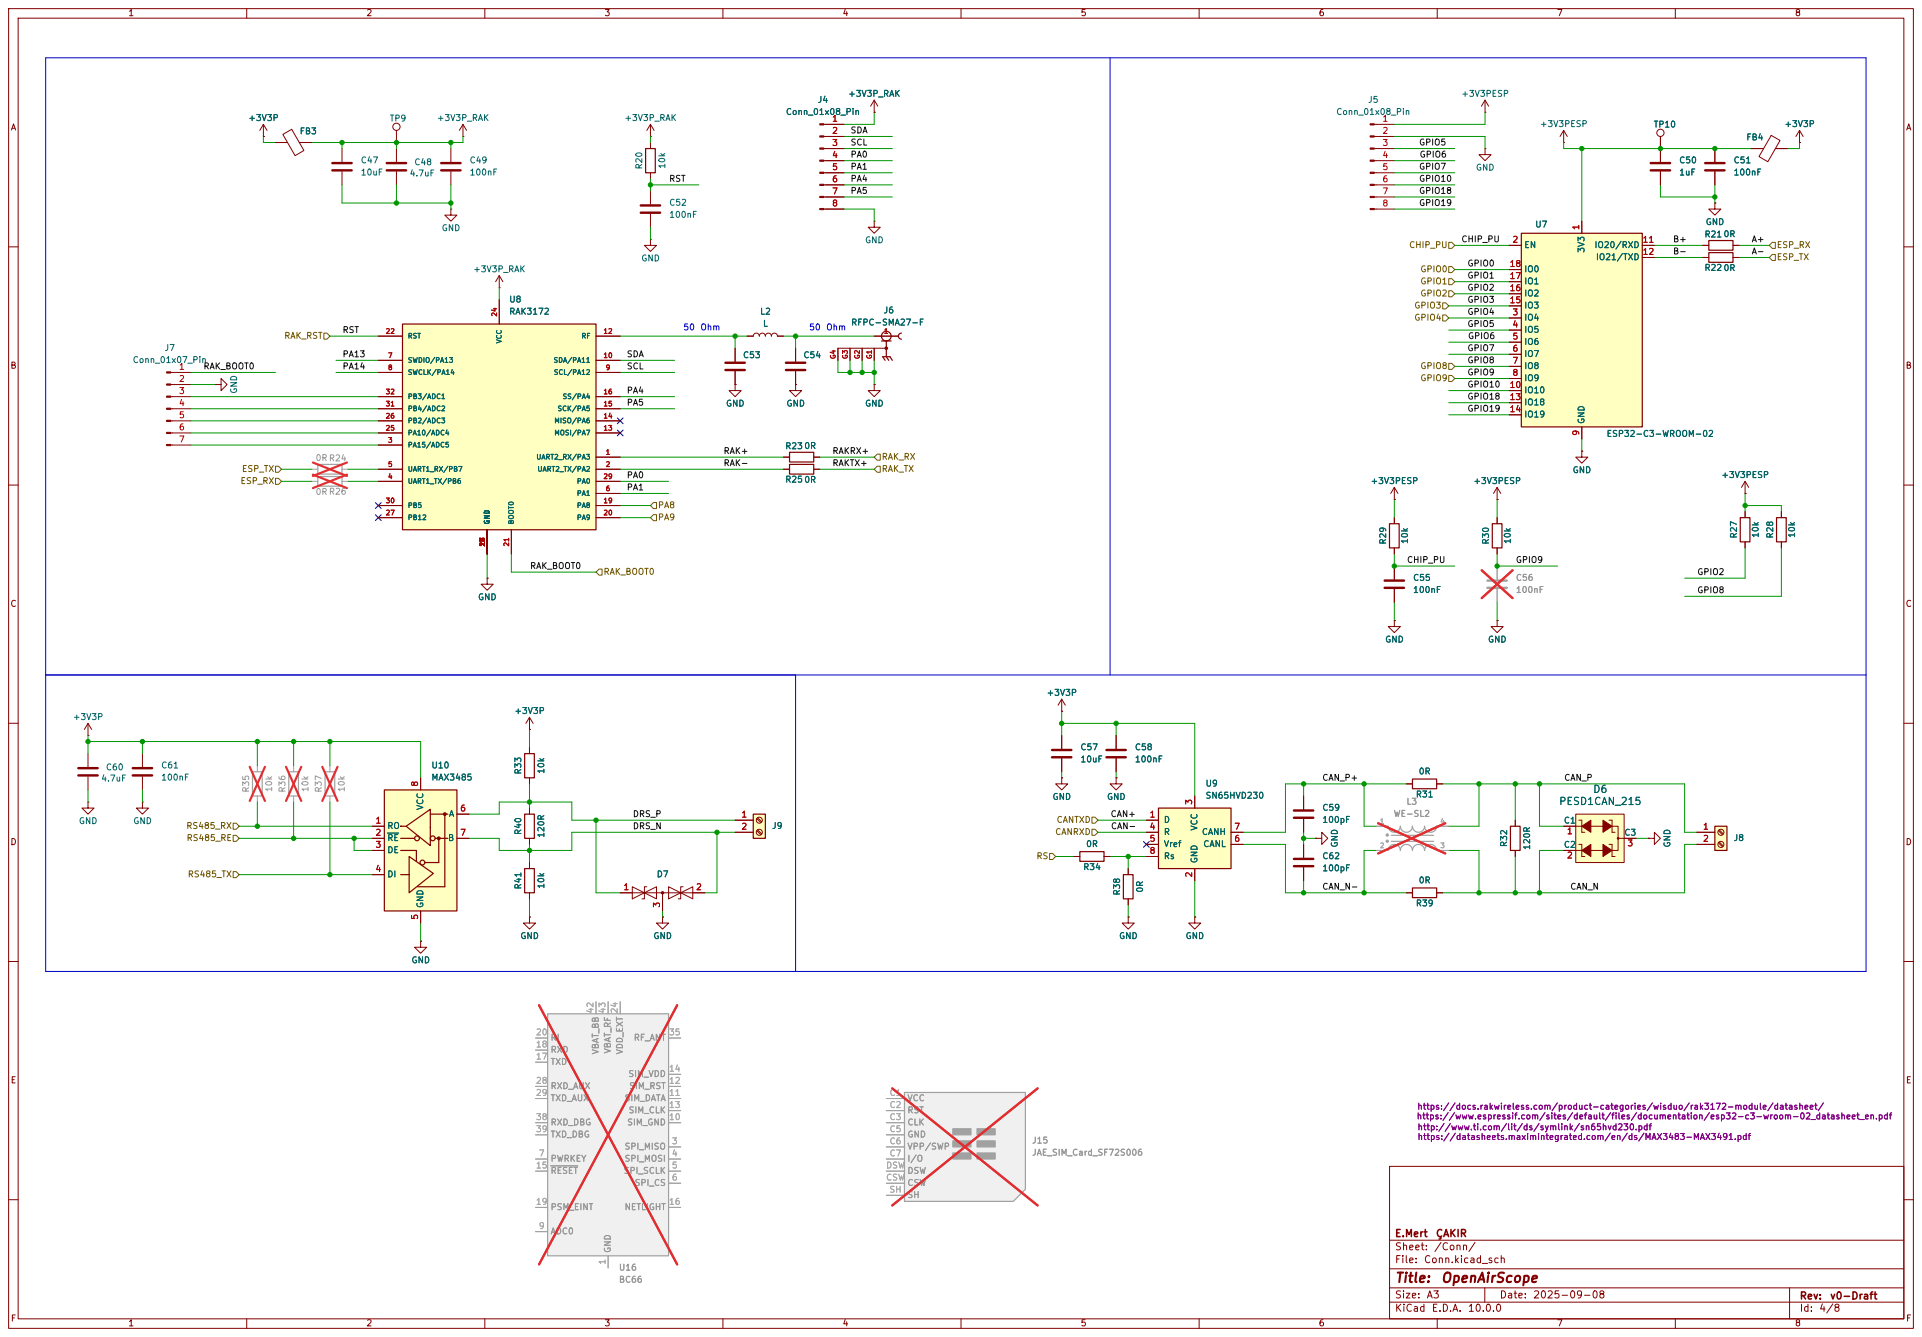
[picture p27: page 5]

https://www.espressif.com/sites/default/files/documentation/esp32-c3-wroom-02_datasheet_en.pdf 3V3

http://www.ti.com/lit/ds/symlink/sn65hvd230.pdf GND +3V3P

http://www.ti.com/lit/ds/symlink/sn65hvd230.pdf D

3 GND R41 10k GND GND U16 BC66 GND

VCC C1 RST C2 CLK C3 GND C5

https://docs.rakwireless.com/product-categories/wisduo/rak3172-module/datasheet/

VPP/SWP C6
I/O C7 CSW CSW DSW DSW

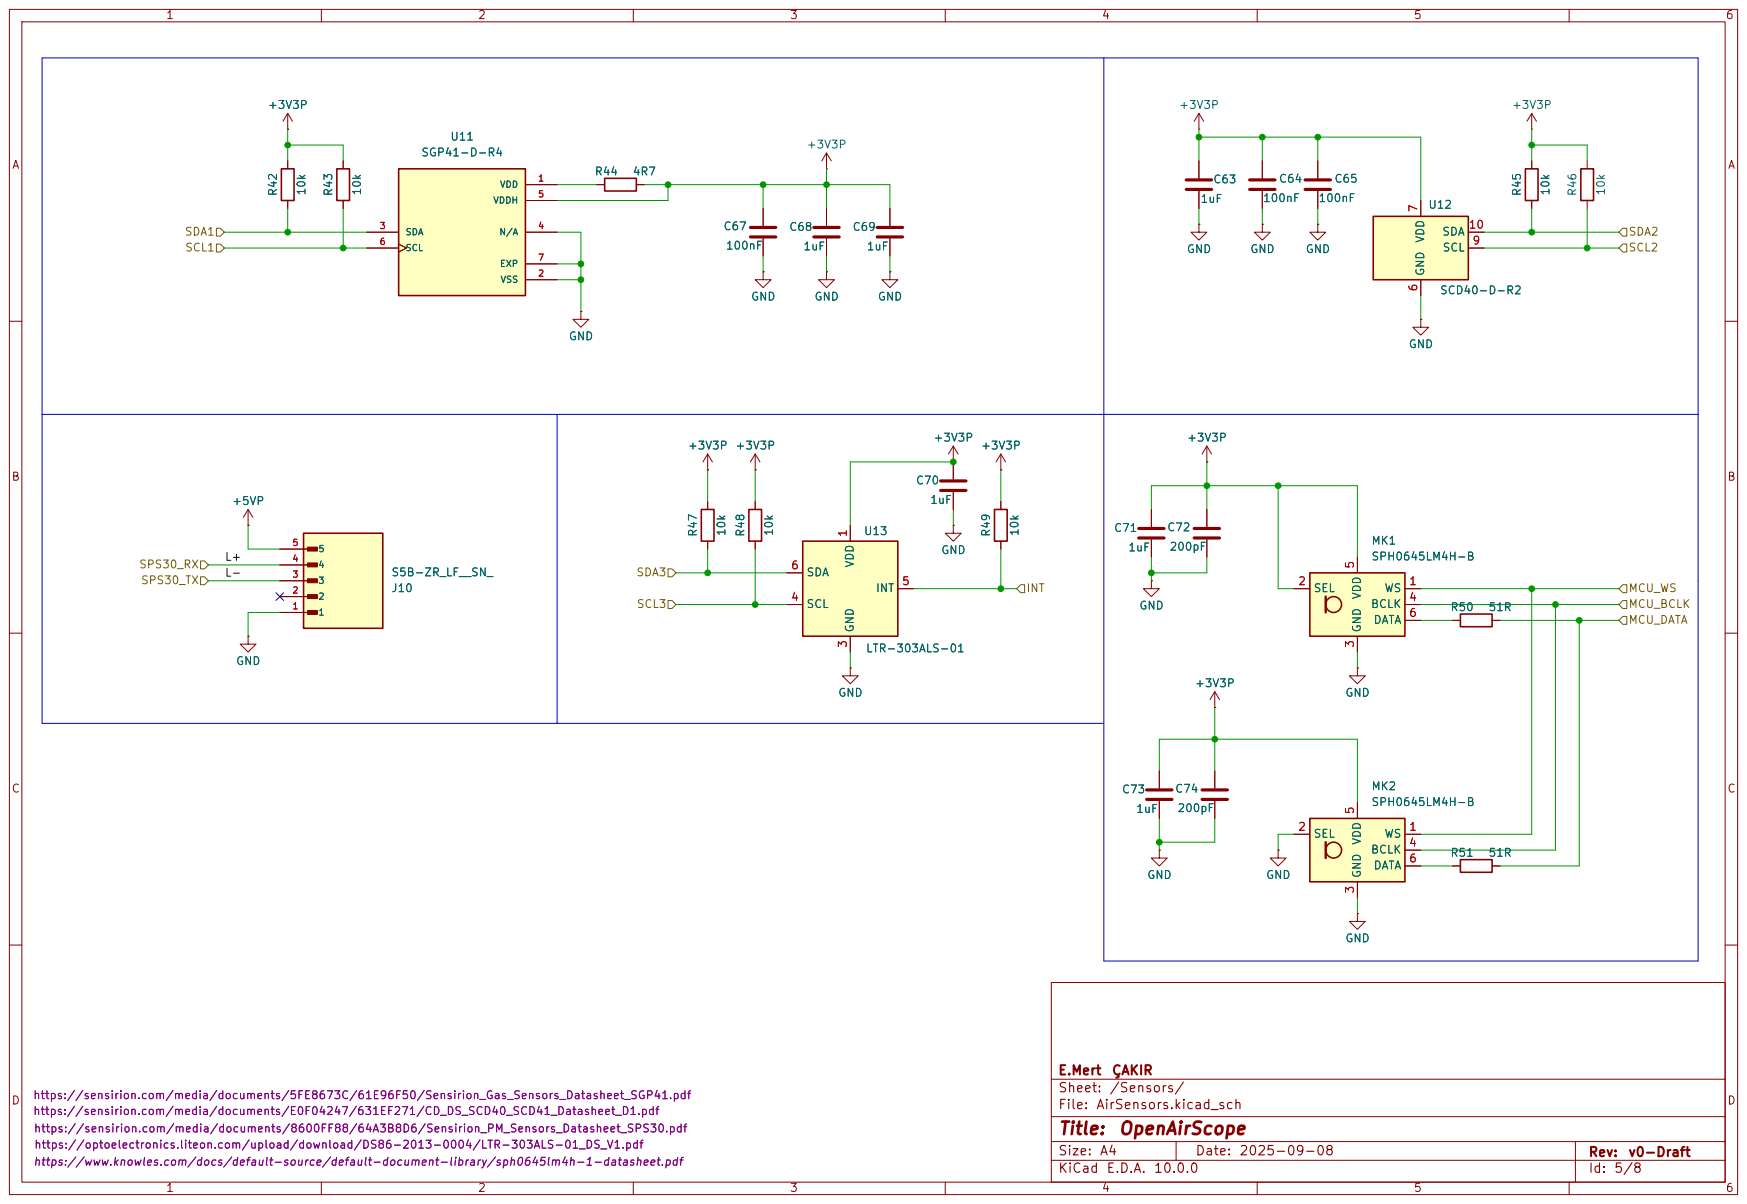
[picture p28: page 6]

S5B-ZR_LF__SN_ https://sensirion.com/media/documents/8600FF88/64A3B8D6/Sensirion_PM_Sensors_Datasheet_SPS30.pdf

https://sensirion.com/media/documents/5FE8673C/61E96F50/Sensirion_Gas_Sensors_Datasheet_SGP41.pdf
https://sensirion.com/media/documents/E0F04247/631EF271/CD_DS_SCD40_SCD41_Datasheet_D1.pdf

https://www.knowles.com/docs/default-source/default-document-library/sph0645lm4h-1-datasheet.pdf

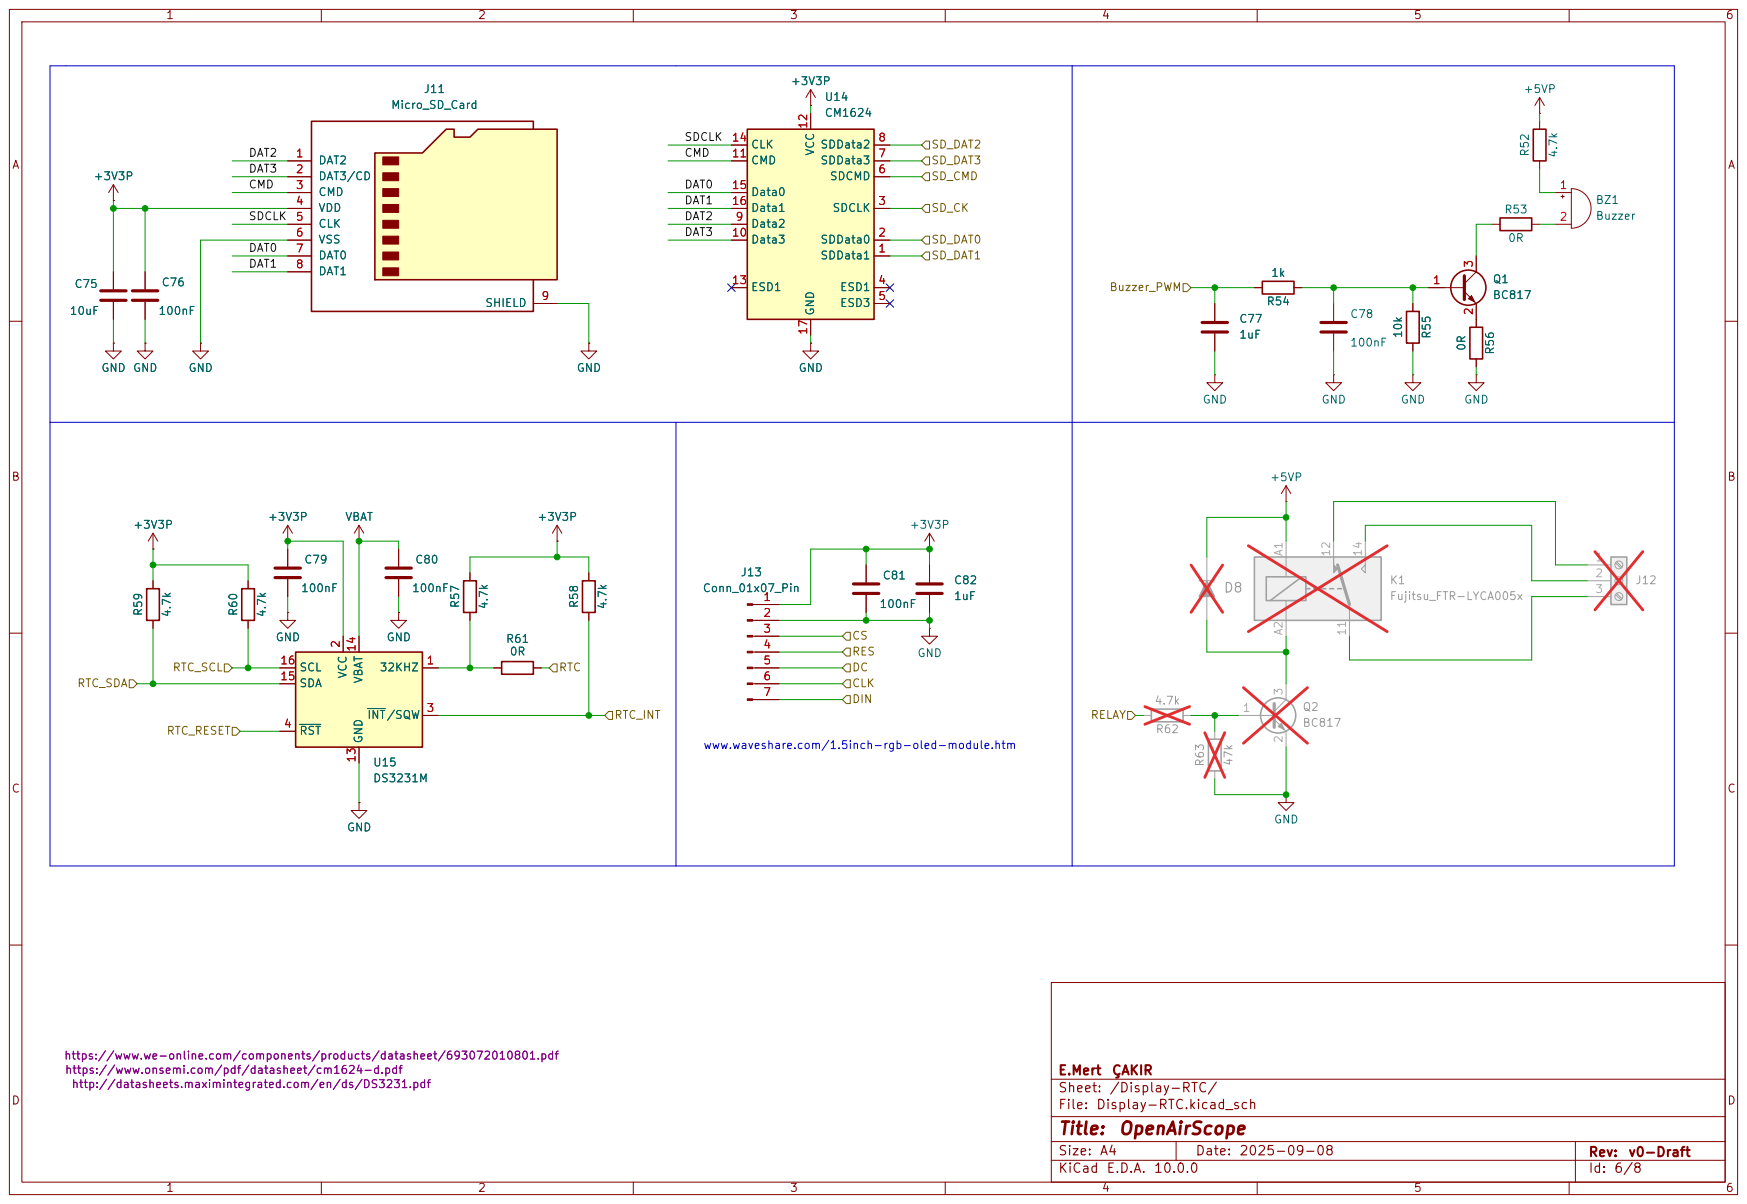
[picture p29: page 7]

https://www.we-online.com/components/products/datasheet/693072010801.pdf
https://www.onsemi.com/pdf/datasheet/cm1624-d.pdf
http://datasheets.maximintegrated.com/en/ds/DS3231.pdf

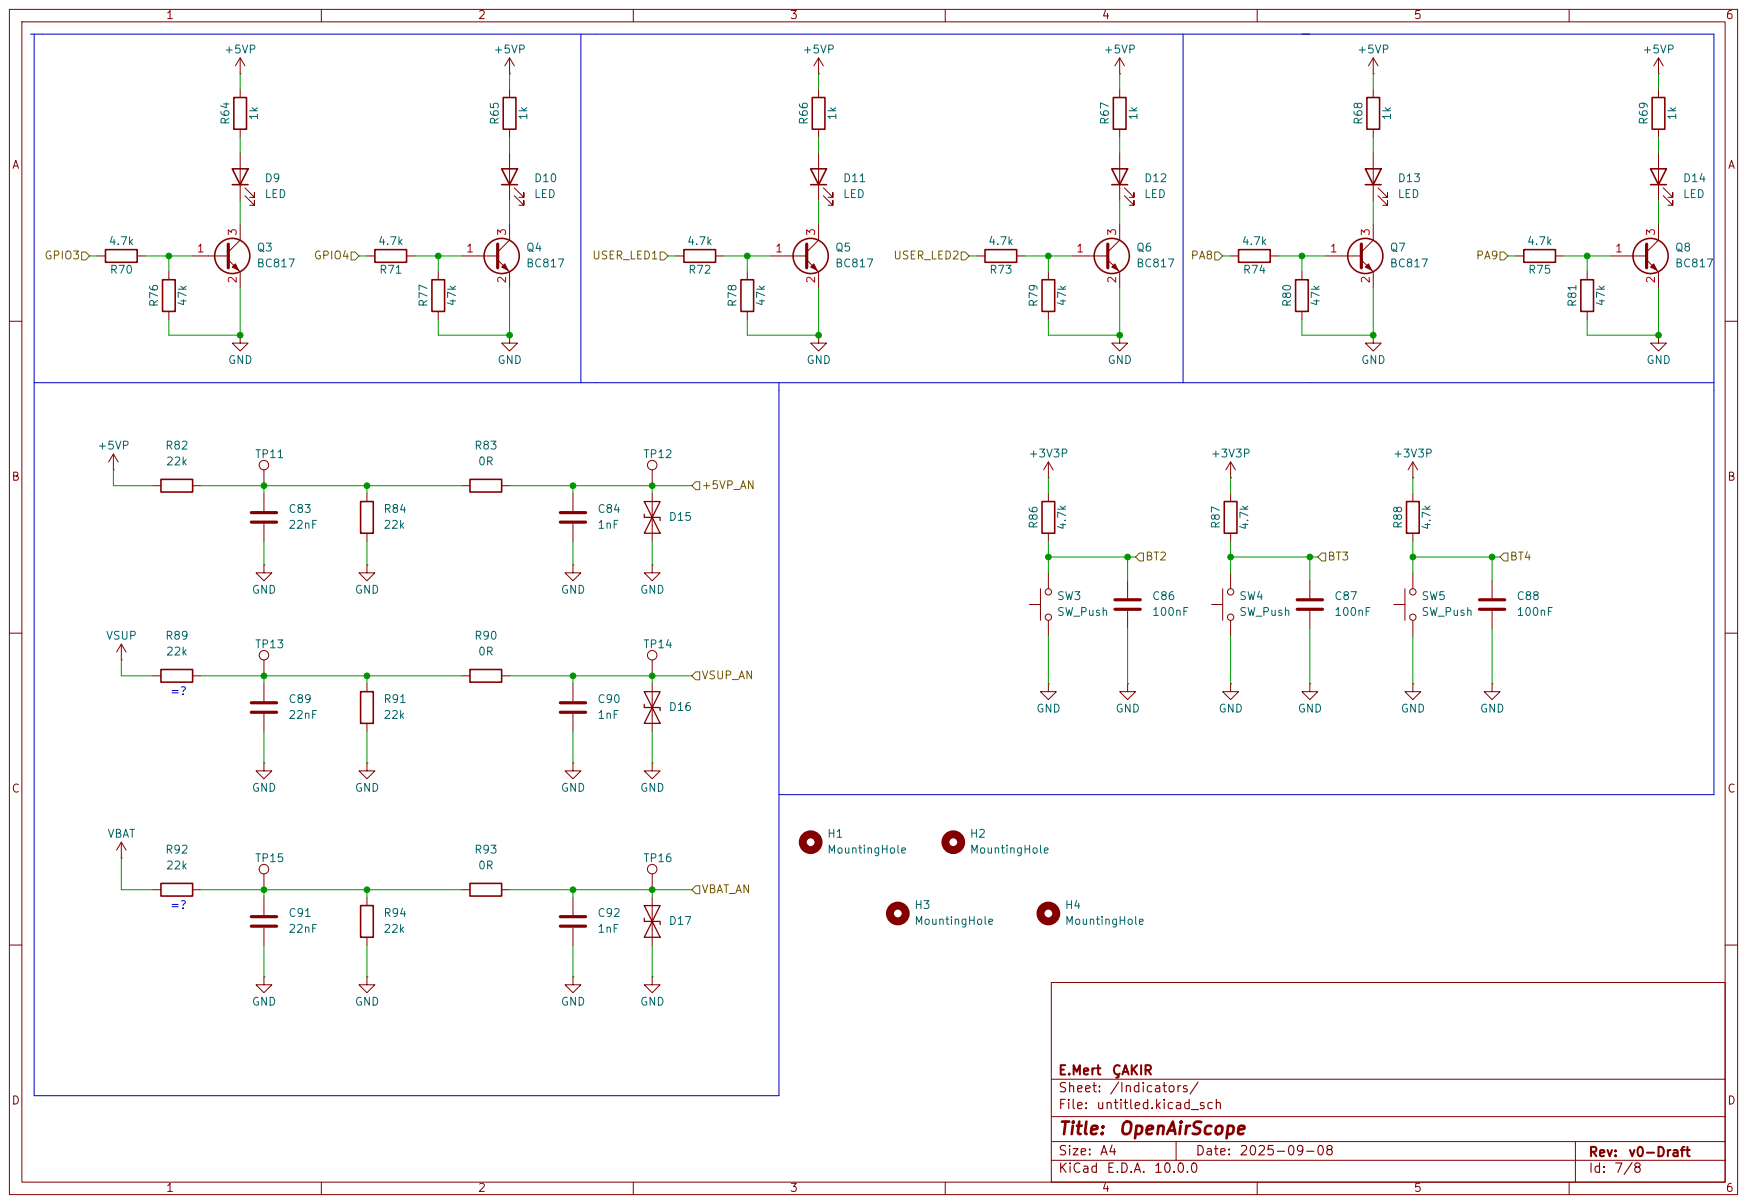
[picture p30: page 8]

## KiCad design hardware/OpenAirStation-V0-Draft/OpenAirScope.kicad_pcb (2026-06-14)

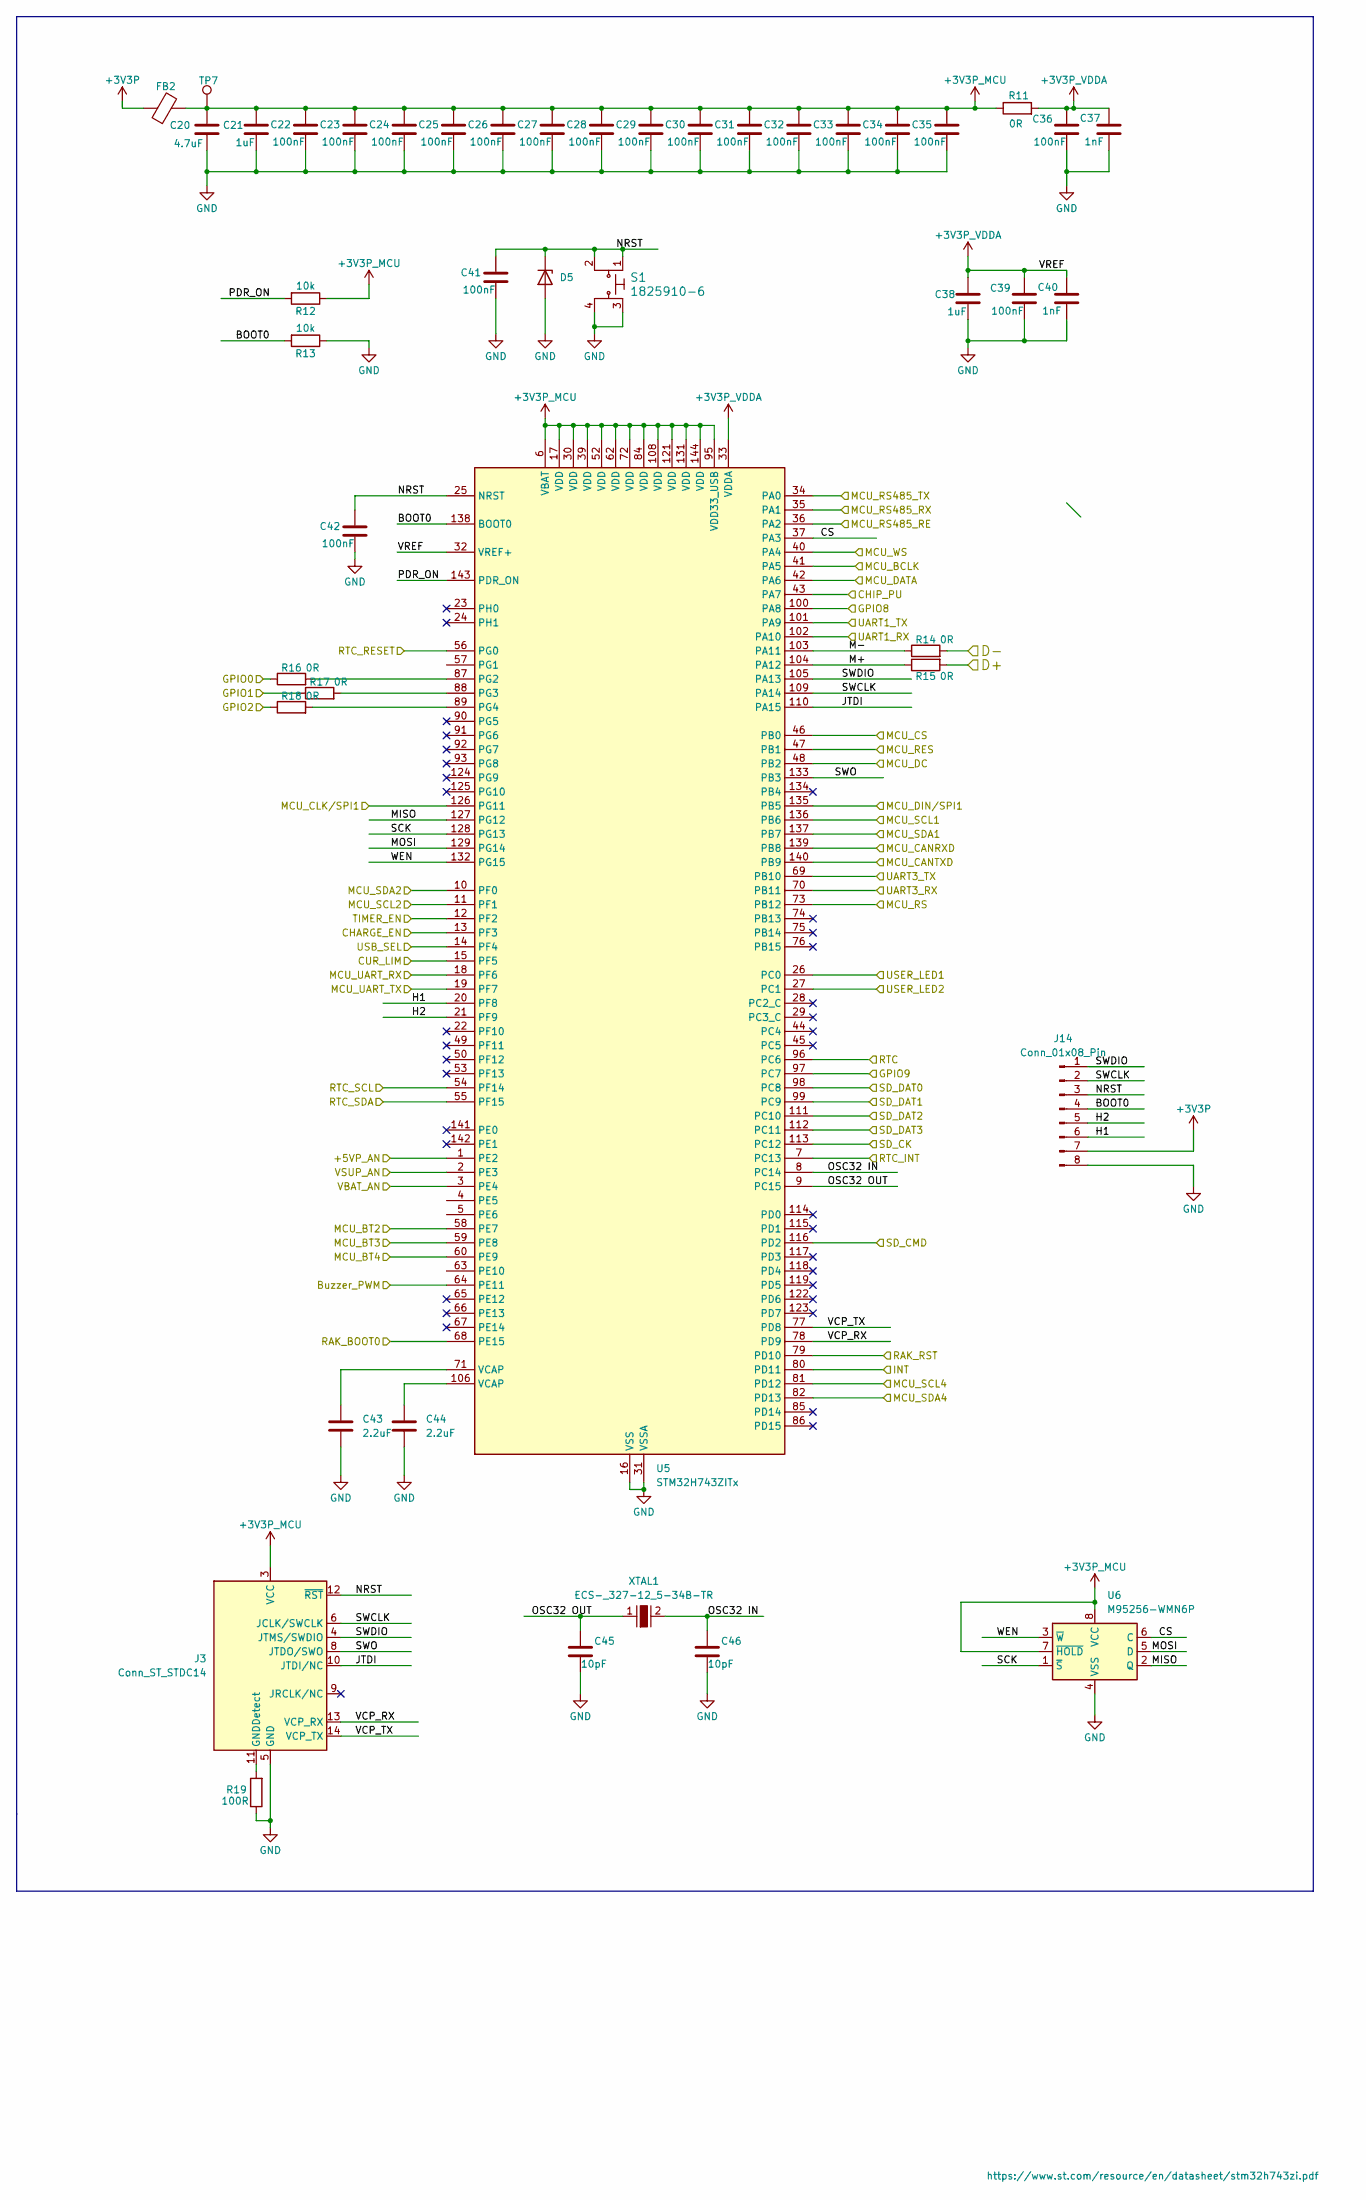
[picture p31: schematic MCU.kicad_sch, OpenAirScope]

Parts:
C20: 4.7uF; C_0805_2012Metric
C21, C38: 1uF; C_1206_3216Metric
C22, C23, C24, C25, C26, C27, C28, C29, C30, C31, C32, C33, C34, C35, C36, C39, C41, C42: 100nF; C_0603_1608Metric
C37, C40: 1nF; C_0603_1608Metric
C43, C44: 2.2uF; C_1206_3216Metric
C45, C46: 10pF; C_0603_1608Metric
D5: PTVS5V0Z1USKYL; Nexperia_DSN1608-2_1.6x0.8mm
FB2: FerriteBead; L_0603_1608Metric
J3: Conn_ST_STDC14; PinHeader_2x07_P1.27mm_Vertical
J14: Conn_01x08_Pin; PinHeader_1x08_P2.54mm_Vertical
R11, R14, R15, R16, R17, R18: 0R; R_0603_1608Metric
R12, R13: 10k; R_0603_1608Metric
R19: 100R; R_0603_1608Metric
S1: 1825910-6; Switch_Tactile_THT_6x6mm; MPN 1825910-6; Digi-Key_PN 450-1650-ND
TP7: TestPoint; TestPoint_Pad_D1.0mm
U5: STM32H743ZITx; LQFP-144_20x20mm_P0.5mm
U6: M95256-WMN6P; SOIC-8_3.9x4.9mm_P1.27mm
XTAL1: ECS-_327-12_5-34B-TR; SMD-2_3.2x1.5mm; MPN ECS-.327-12.5-34B-TR; Digi-Key_PN XC1617CT-ND

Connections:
+3V3P: FB2.1, J14.7; also elsewhere on the board
+3V3P_MCU: C20.1, C21.1, C22.2, C23.2, C24.2, C25.2, C26.2, C27.2, C28.2, C29.2, C30.2, C31.2, C32.2, C33.2, C34.2, C35.2, FB2.2, J3.3 (VCC), R11.1, R12.1, TP7.1, U5.6 (VBAT), U5.17 (VDD), U5.30 (VDD), U5.39 (VDD), U5.52 (VDD), U5.62 (VDD), U5.72 (VDD), U5.84 (VDD), U5.95 (VDD33_USB), U5.108 (VDD), U5.121 (VDD), U5.131 (VDD), U5.144 (VDD), U6.7 (~HOLD), U6.8 (VCC)
+3V3P_VDDA: C36.2, C37.1, C38.1, C39.2, C40.1, R11.2, U5.32 (VREF+), U5.33 (VDDA)
/Conn/A+: U5.101 (PA9); also elsewhere on the board
/Conn/A-: U5.102 (PA10); also elsewhere on the board
/Conn/CAN+: U5.139 (PB8); also elsewhere on the board
/Conn/CAN-: U5.140 (PB9); also elsewhere on the board
/Conn/CHIP_PU: U5.43 (PA7); also elsewhere on the board
/Conn/GPIO0: R16.1; also elsewhere on the board
/Conn/GPIO1: R17.1; also elsewhere on the board
/Conn/GPIO2: R18.1; also elsewhere on the board
/Conn/GPIO8: U5.100 (PA8); also elsewhere on the board
/Conn/GPIO9: U5.97 (PC7); also elsewhere on the board
/Conn/RAKRX+: U5.69 (PB10); also elsewhere on the board
/Conn/RAKTX+: U5.70 (PB11); also elsewhere on the board
/Conn/RAK_BOOT0: U5.68 (PE15); also elsewhere on the board
/Conn/RS: U5.73 (PB12); also elsewhere on the board
/Conn/RS485_RE: U5.36 (PA2); also elsewhere on the board
/Conn/RS485_RX: U5.34 (PA0); also elsewhere on the board
/Conn/RS485_TX: U5.35 (PA1); also elsewhere on the board
/Conn/RST: U5.79 (PD10); also elsewhere on the board
/Display-RTC/Buzzer_PWM: U5.64 (PE11); also elsewhere on the board
/Display-RTC/CLK: U5.126 (PG11); also elsewhere on the board
/Display-RTC/CS: U5.46 (PB0); also elsewhere on the board
/Display-RTC/DC: U5.48 (PB2); also elsewhere on the board
/Display-RTC/DIN: U5.135 (PB5); also elsewhere on the board
/Display-RTC/RES: U5.47 (PB1); also elsewhere on the board
/Display-RTC/RTC: U5.96 (PC6); also elsewhere on the board
/Display-RTC/RTC_INT: U5.7 (PC13); also elsewhere on the board
/Display-RTC/RTC_RESET: U5.56 (PG0); also elsewhere on the board
/Display-RTC/RTC_SCL: U5.54 (PF14); also elsewhere on the board
/Display-RTC/RTC_SDA: U5.55 (PF15); also elsewhere on the board
/Display-RTC/SD_CK: U5.113 (PC12); also elsewhere on the board
/Display-RTC/SD_CMD: U5.116 (PD2); also elsewhere on the board
/Display-RTC/SD_DAT0: U5.98 (PC8); also elsewhere on the board
/Display-RTC/SD_DAT1: U5.99 (PC9); also elsewhere on the board
/Display-RTC/SD_DAT2: U5.111 (PC10); also elsewhere on the board
/Display-RTC/SD_DAT3: U5.112 (PC11); also elsewhere on the board
/Indicators/+5VP_AN: U5.1 (PE2); also elsewhere on the board
/Indicators/BT2: U5.58 (PE7); also elsewhere on the board
/Indicators/BT3: U5.59 (PE8); also elsewhere on the board
/Indicators/BT4: U5.60 (PE9); also elsewhere on the board
/Indicators/USER_LED1: U5.26 (PC0); also elsewhere on the board
/Indicators/USER_LED2: U5.27 (PC1); also elsewhere on the board
/Indicators/VBAT_AN: U5.3 (PE4); also elsewhere on the board
/Indicators/VSUP_AN: U5.2 (PE3); also elsewhere on the board
/MCU/BOOT0: J14.4, R13.2, U5.138 (BOOT0)
/MCU/CHARGE_EN: U5.13 (PF3); also elsewhere on the board
/MCU/CS: U5.37 (PA3), U6.6 (C)
/MCU/CUR_LIM: U5.15 (PF5); also elsewhere on the board
/MCU/D+: R15.2; also elsewhere on the board
/MCU/D-: R14.2; also elsewhere on the board
/MCU/H1: J14.6, U5.20 (PF8)
/MCU/H2: J14.5, U5.21 (PF9)
/MCU/INT: U5.80 (PD11); also elsewhere on the board
/MCU/JTDI: J3.10 (JTDI/NC), U5.110 (PA15)
/MCU/M+: R15.1, U5.104 (PA12)
/MCU/M-: R14.1, U5.103 (PA11)
/MCU/MCU_BCLK: U5.41 (PA5); also elsewhere on the board
/MCU/MCU_DATA: U5.42 (PA6); also elsewhere on the board
/MCU/MCU_SCL1: U5.136 (PB6); also elsewhere on the board
/MCU/MCU_SCL2: U5.11 (PF1); also elsewhere on the board
/MCU/MCU_SCL4: U5.81 (PD12); also elsewhere on the board
/MCU/MCU_SDA1: U5.137 (PB7); also elsewhere on the board
/MCU/MCU_SDA2: U5.10 (PF0); also elsewhere on the board
/MCU/MCU_SDA4: U5.82 (PD13); also elsewhere on the board
/MCU/MCU_WS: U5.40 (PA4); also elsewhere on the board
/MCU/MISO: U5.127 (PG12), U6.2 (Q)
/MCU/MOSI: U5.129 (PG14), U6.5 (D)
/MCU/NRST: C41.2, C42.2, D5.1 (K), J3.12 (~RST), J14.3, S1.1, S1.2, U5.25 (NRST)
/MCU/OSC32 IN: C46.2, U5.8 (PC14), XTAL1.2
/MCU/OSC32 OUT: C45.2, U5.9 (PC15), XTAL1.1
/MCU/PDR_ON: R12.2, U5.143 (PDR_ON)
/MCU/SCK: U5.128 (PG13), U6.1 (~S)
/MCU/SWCLK: J3.6 (JCLK/SWCLK), J14.2, U5.109 (PA14)
/MCU/SWDIO: J3.4 (JTMS/SWDIO), J14.1, U5.105 (PA13)
/MCU/SWO: J3.8 (JTDO/SWO), U5.133 (PB3)
/MCU/TIMER_EN: U5.12 (PF2); also elsewhere on the board
/MCU/USB_SEL: U5.14 (PF4); also elsewhere on the board
/MCU/VCP_RX: J3.13 (VCP_RX), U5.78 (PD9)
/MCU/VCP_TX: J3.14 (VCP_TX), U5.77 (PD8)
/MCU/WEN: U5.132 (PG15), U6.3 (~W)
/Sensors/L+: U5.19 (PF7); also elsewhere on the board
/Sensors/L-: U5.18 (PF6); also elsewhere on the board
GND: C20.2, C21.2, C22.1, C23.1, C24.1, C25.1, C26.1, C27.1, C28.1, C29.1, C30.1, C31.1, C32.1, C33.1, C34.1, C35.1, C36.1, C37.2, C38.2, C39.1, C40.2, C41.1, C42.1, C43.2, C44.2, C45.1, C46.1, D5.2 (A), J3.5 (GND), J3.7 (GND), J14.8, R13.1, R19.1, S1.3, S1.4, U5.16 (VSS), U5.31 (VSSA), U5.38 (VSS), U5.51 (VSS), U5.61 (VSS), U5.83 (VSS), U5.94 (VSS), U5.107 (VSS), U5.120 (VSS), U5.130 (VSS), U6.4 (VSS); also elsewhere on the board
unnamed: C43.1, U5.71 (VCAP)
unnamed: C44.1, U5.106 (VCAP)
unnamed: J3.11 (GNDDetect), R19.2
unnamed: R16.2, U5.87 (PG2)
unnamed: R17.2, U5.88 (PG3)
unnamed: R18.2, U5.89 (PG4)

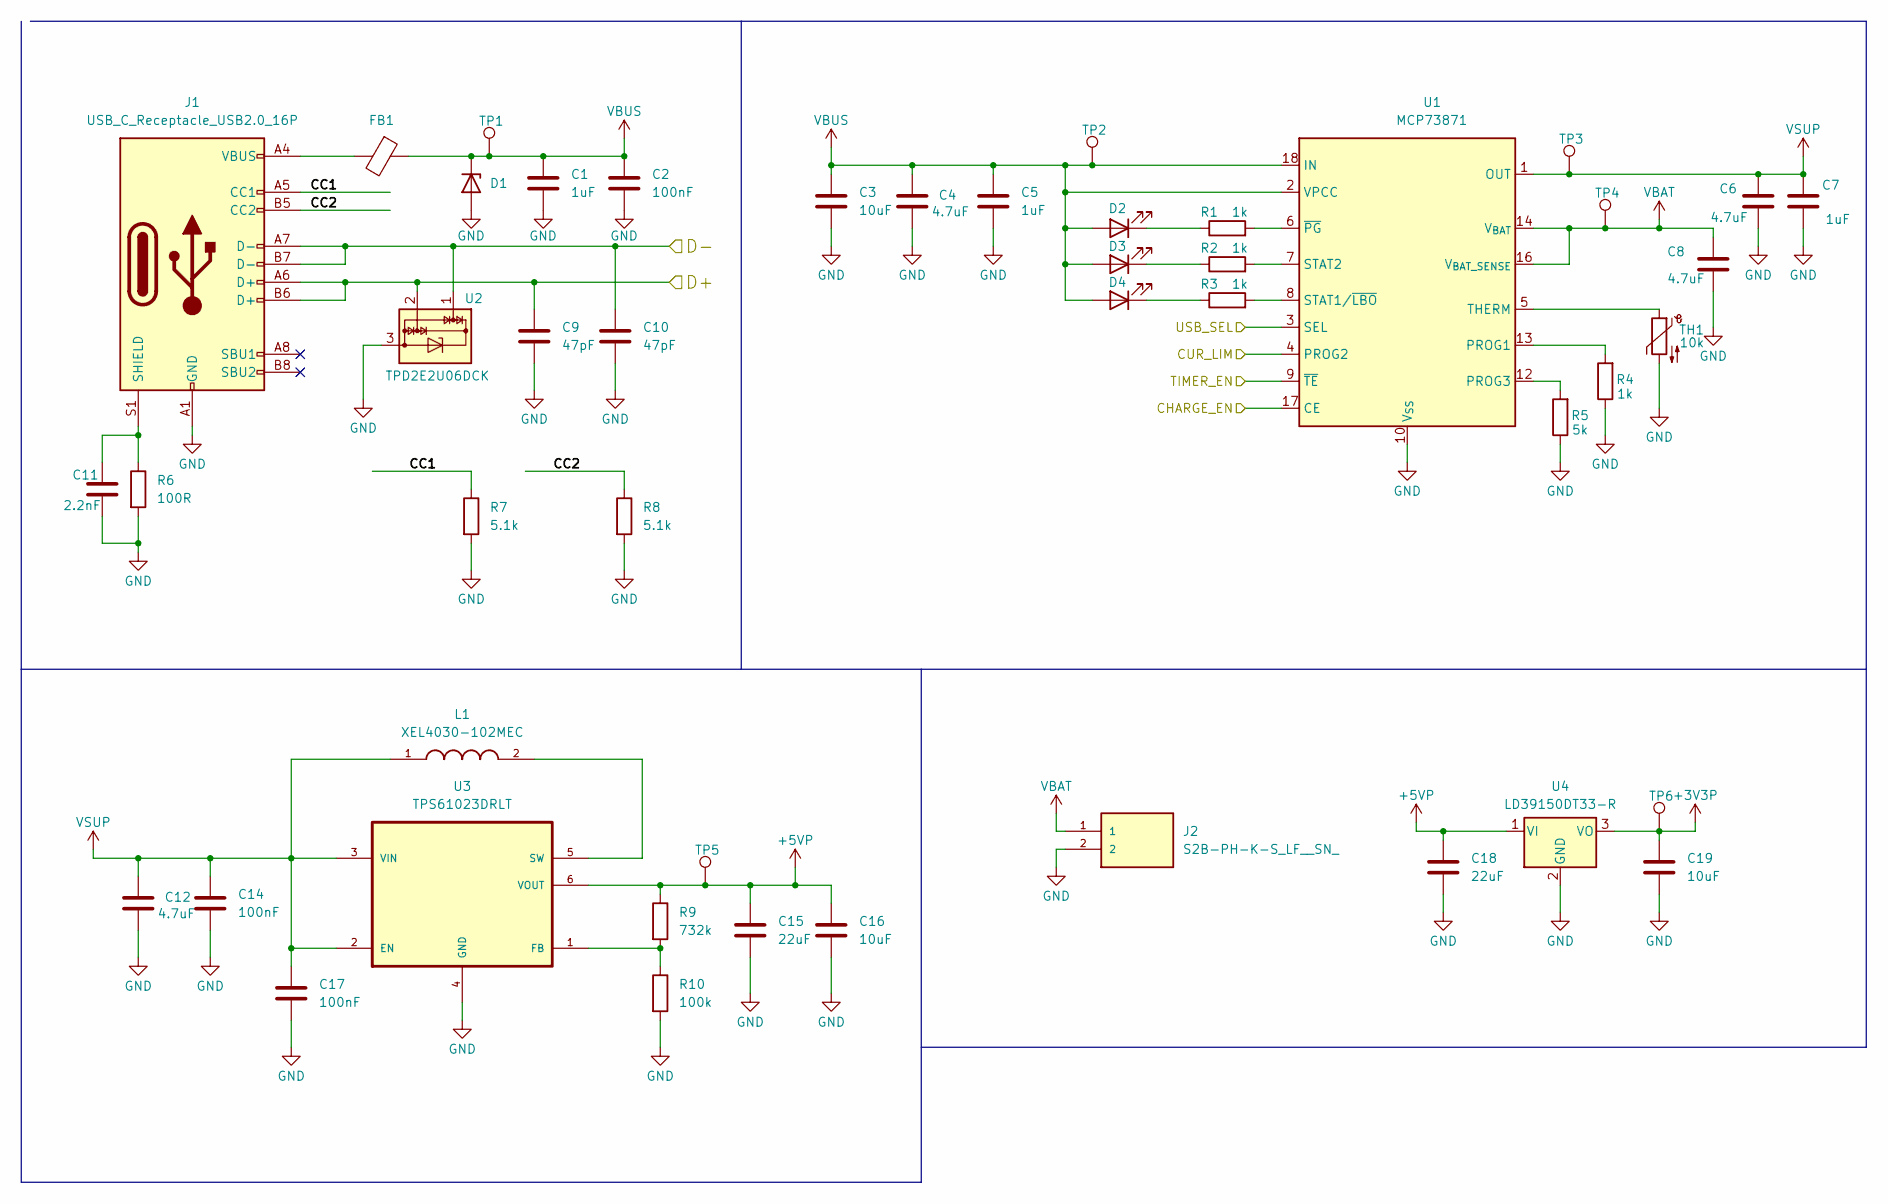
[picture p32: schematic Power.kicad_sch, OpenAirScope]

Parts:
C1, C5, C7: 1uF; C_1206_3216Metric
C2, C14, C17: 100nF; C_0603_1608Metric
C3, C16, C19: 10uF; C_1206_3216Metric
C4, C6, C8, C12: 4.7uF; C_0805_2012Metric
C9, C10: 47pF; C_0603_1608Metric
C11: 2.2nF; C_0805_2012Metric
C15, C18: 22uF; C_1206_3216Metric
D1: PTVS5V0Z1USKYL; Nexperia_DSN1608-2_1.6x0.8mm
D2, D3, D4: LED; LED_0603_1608Metric
FB1: FerriteBead; L_0603_1608Metric
J1: USB_C_Receptacle_USB2.0_16P; USB_C_Receptacle_GCT_USB4110
J2: S2B-PH-K-S_LF__SN_; JST_S2B-PH-K-S_LF__SN_
L1: XEL4030-102MEC; IND_XEL4030-102MEC; PARTREV 05/10/24
R1, R2, R3, R4: 1k; R_0603_1608Metric
R5: 5k; R_0603_1608Metric
R6: 100R; R_0603_1608Metric
R7, R8: 5.1k; R_0603_1608Metric
R9: 732k; R_0603_1608Metric
R10: 100k; R_0603_1608Metric
TH1: 10k; R_0603_1608Metric
TP1, TP2, TP3, TP4, TP5, TP6: TestPoint; TestPoint_Pad_D1.0mm
U1: MCP73871; QFN-20-1EP_4x4mm_P0.5mm_EP2.5x2.5mm_ThermalVias
U2: TPD2E2U06DCK; SOT-323_SC-70
U3: TPS61023DRLT; SOT50P160X60-6N
U4: LD39150DT33-R; TO-252-3_TabPin2

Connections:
+3V3P: C19.1, TP6.1, U4.3 (VO); also elsewhere on the board
+5VP: C15.1, C16.1, C18.1, R9.1, TP5.1, U3.6 (VOUT), U4.1 (VI); also elsewhere on the board
/MCU/CHARGE_EN: U1.17 (CE); also elsewhere on the board
/MCU/CUR_LIM: U1.4 (PROG2); also elsewhere on the board
/MCU/D+: C9.1, J1.A6 (D+), J1.B6 (D+), U2.2; also elsewhere on the board
/MCU/D-: C10.1, J1.A7 (D-), J1.B7 (D-), U2.1; also elsewhere on the board
/MCU/TIMER_EN: U1.9 (~TE); also elsewhere on the board
/MCU/USB_SEL: U1.3 (SEL); also elsewhere on the board
/Power/CC1: J1.A5 (CC1), R7.1
/Power/CC2: J1.B5 (CC2), R8.1
GND: C1.2, C2.2, C3.2, C4.2, C5.2, C6.2, C7.2, C8.2, C9.2, C10.2, C11.2, C12.2, C14.2, C15.2, C16.2, C17.2, C18.2, C19.2, D1.2 (A), J1.A1 (GND), J1.A12 (GND), J1.B1 (GND), J1.B12 (GND), J2.2, R4.1, R5.1, R6.2, R7.2, R8.2, R10.2, TH1.2, U1.10 (V_{SS}), U1.11 (V_{SS}), U1.21 (V_{SS}), U2.3, U3.4 (GND), U4.2 (GND); also elsewhere on the board
unnamed: D2.1 (K), R1.1
unnamed: D3.1 (K), R2.1
unnamed: D4.1 (K), R3.1
unnamed: FB1.2, J1.A4 (VBUS), J1.A9 (VBUS), J1.B4 (VBUS), J1.B9 (VBUS)
unnamed: C11.1, J1.S1 (SHIELD), R6.1
unnamed: R4.2, U1.13 (PROG1)
unnamed: R5.2, U1.12 (PROG3)
unnamed: R3.2, U1.8 (STAT1/~LBO)
unnamed: R2.2, U1.7 (STAT2)
unnamed: TH1.1, U1.5 (THERM)
unnamed: R1.2, U1.6 (~PG)
unnamed: R9.2, R10.1, U3.1 (FB)
unnamed: L1.2, U3.5 (SW)
VBAT: C8.1, J2.1, TP4.1, U1.14 (V_{BAT}), U1.15 (V_{BAT}), U1.16 (V_{BAT_SENSE}); also elsewhere on the board
VBUS: C1.1, C2.1, C3.1, C4.1, C5.1, D1.1 (K), D2.2 (A), D3.2 (A), D4.2 (A), FB1.1, TP1.1, TP2.1, U1.2 (VPCC), U1.18 (IN), U1.19 (IN)
VSUP: C6.1, C7.1, C12.1, C14.1, C17.1, L1.1, TP3.1, U1.1 (OUT), U1.20 (OUT), U3.2 (EN), U3.3 (VIN); also elsewhere on the board

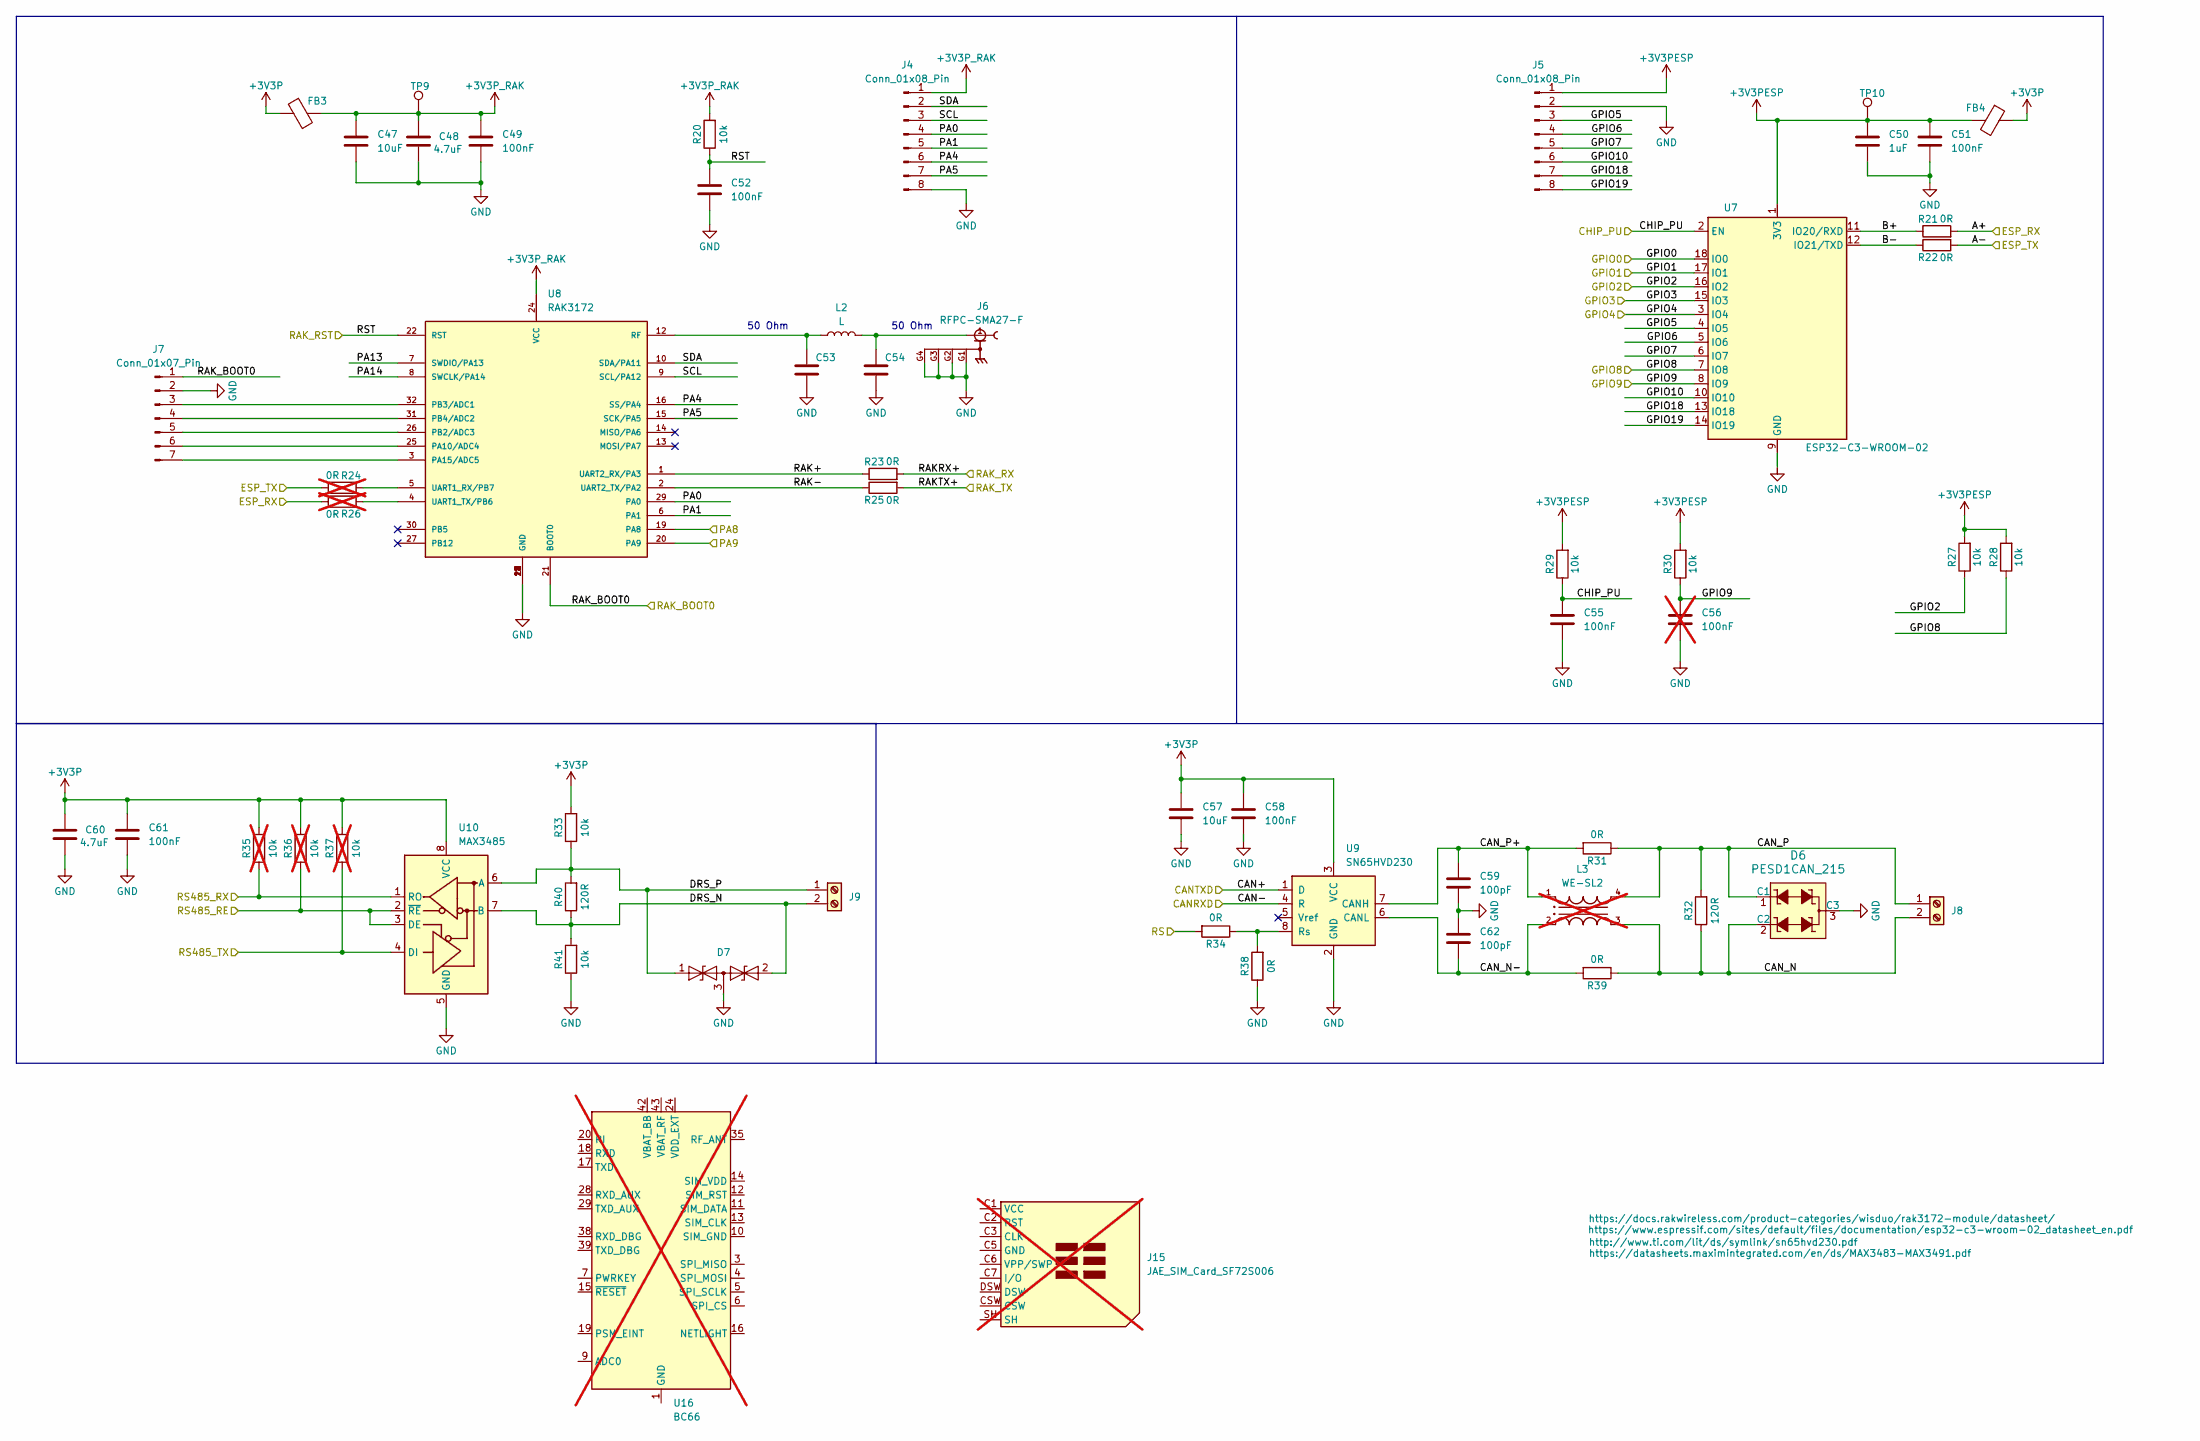
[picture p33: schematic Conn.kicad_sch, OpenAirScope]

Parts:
C47, C57: 10uF; C_1206_3216Metric
C48, C60: 4.7uF; C_0805_2012Metric
C49, C51, C52, C55, C58, C61: 100nF; C_0603_1608Metric
C50: 1uF; C_1206_3216Metric
C53, C54: C_0402_1005Metric
C56: 100nF; C_0603_1608Metric; not fitted
C59, C62: 100pF; C_0603_1608Metric
D6: PESD1CAN_215; SOT-23-3; MPN PESD1CAN,215; Digi-Key_PN 1727-3817-1-ND
D7: SM712_SOT23; SOT-23
FB3, FB4: FerriteBead; L_0603_1608Metric
J4, J5: Conn_01x08_Pin; PinHeader_1x08_P2.54mm_Vertical
J6: RFPC-SMA27-F; GRADCONN_RFPC-SMA27-F; PARTREV 1.0
J7: Conn_01x07_Pin; PinHeader_1x07_P2.54mm_Vertical
J8, J9: Screw_Terminal_01x02; TerminalBlock_RND_205-00045_1x02_P5.00mm_Horizontal
J15: JAE_SIM_Card_SF72S006; SD_Card_Device_16mm_SlotDepth; not fitted
L2: L; L_0603_1608Metric
L3: WE-SL2; not fitted
R20, R27, R28, R29, R30, R33, R41: 10k; R_0603_1608Metric
R21, R22, R23, R25, R31, R34, R38, R39: 0R; R_0603_1608Metric
R24, R26: 0R; R_0603_1608Metric; not fitted
R32, R40: 120R; R_0603_1608Metric
R35, R36, R37: 10k; R_0603_1608Metric; not fitted
TP9, TP10: TestPoint; TestPoint_Pad_D1.0mm
U7: ESP32-C3-WROOM-02
U8: RAK3172
U9: SN65HVD230; SOIC-8_3.9x4.9mm_P1.27mm
U10: MAX3485; SOIC-8_3.9x4.9mm_P1.27mm
U16: BC66; Quectel_BC66; not fitted

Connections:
+3V3P: C57.1, C58.1, C60.1, C61.1, FB3.1, FB4.1, R33.2, R35.2, R36.2, R37.2, U9.3 (VCC), U10.8 (VCC); also elsewhere on the board
+3V3PESP: C50.1, C51.1, FB4.2, J5.1, R27.2, R28.2, R29.2, R30.2, TP10.1, U7.1 (3V3)
+3V3P_RAK: C47.1, C48.1, C49.1, FB3.2, J4.1, R20.2, TP9.1, U8.24 (VCC)
/Conn/A+: R21.2, R26.2; also elsewhere on the board
/Conn/A-: R22.2, R24.2; also elsewhere on the board
/Conn/B+: R21.1, U7.11 (IO20/RXD)
/Conn/B-: R22.1, U7.12 (IO21/TXD)
/Conn/CAN+: U9.1 (D); also elsewhere on the board
/Conn/CAN-: U9.4 (R); also elsewhere on the board
/Conn/CAN_N: D6.2 (C2), J8.2, L3.3, R32.1, R39.1
/Conn/CAN_N-: C62.2, L3.2, R39.2, U9.6 (CANL)
/Conn/CAN_P: D6.1 (C1), J8.1, L3.4, R31.1, R32.2
/Conn/CAN_P+: C59.1, L3.1, R31.2, U9.7 (CANH)
/Conn/CHIP_PU: C55.1, R29.1, U7.2 (EN); also elsewhere on the board
/Conn/DRS_N: D7.2 (A2), J9.2, R40.1, R41.2, U10.7 (B)
/Conn/DRS_P: D7.1 (A1), J9.1, R33.1, R40.2, U10.6 (A)
/Conn/GPIO0: U7.18 (IO0); also elsewhere on the board
/Conn/GPIO1: U7.17 (IO1); also elsewhere on the board
/Conn/GPIO2: R27.1, U7.16 (IO2); also elsewhere on the board
/Conn/GPIO3: U7.15 (IO3); also elsewhere on the board
/Conn/GPIO4: U7.3 (IO4); also elsewhere on the board
/Conn/GPIO5: J5.3, U7.4 (IO5)
/Conn/GPIO6: J5.4, U7.5 (IO6)
/Conn/GPIO7: J5.5, U7.6 (IO7)
/Conn/GPIO8: R28.1, U7.7 (IO8); also elsewhere on the board
/Conn/GPIO9: C56.1, R30.1, U7.8 (IO9); also elsewhere on the board
/Conn/GPIO10: J5.6, U7.10 (IO10)
/Conn/GPIO18: J5.7, U7.13 (IO18)
/Conn/GPIO19: J5.8, U7.14 (IO19)
/Conn/PA0: J4.4, U8.29 (PA0)
/Conn/PA1: J4.5, U8.6 (PA1)
/Conn/PA4: J4.6, U8.16 (SS/PA4)
/Conn/PA5: J4.7, U8.15 (SCK/PA5)
/Conn/PA8: U8.19 (PA8); also elsewhere on the board
/Conn/PA9: U8.20 (PA9); also elsewhere on the board
/Conn/PA13: U8.7 (SWDIO/PA13)
/Conn/PA14: U8.8 (SWCLK/PA14)
/Conn/RAK+: R23.1, U8.1 (UART2_RX/PA3)
/Conn/RAK-: R25.1, U8.2 (UART2_TX/PA2)
/Conn/RAKRX+: R23.2; also elsewhere on the board
/Conn/RAKTX+: R25.2; also elsewhere on the board
/Conn/RAK_BOOT0: J7.1, U8.21 (BOOT0); also elsewhere on the board
/Conn/RS: R34.2; also elsewhere on the board
/Conn/RS485_RE: R36.1, U10.2 (~RE), U10.3 (DE); also elsewhere on the board
/Conn/RS485_RX: R35.1, U10.1 (RO); also elsewhere on the board
/Conn/RS485_TX: R37.1, U10.4 (DI); also elsewhere on the board
/Conn/RST: C52.1, R20.1, U8.22 (RST); also elsewhere on the board
/Conn/SCL: J4.3, U8.9 (SCL/PA12)
/Conn/SDA: J4.2, U8.10 (SDA/PA11)
GND: C47.2, C48.2, C49.2, C50.2, C51.2, C52.2, C53.2, C54.2, C55.2, C56.2, C57.2, C58.2, C59.2, C60.2, C61.2, C62.1, D6.3 (C3), D7.3 (common), J4.8, J5.2, J6.G1, J6.G2, J6.G3, J6.G4, J7.2, R38.1, R41.1, U7.9 (GND), U7.19 (GND), U8.11 (GND), U8.17 (GND), U8.18 (GND), U8.23 (GND), U8.28 (GND), U9.2 (GND), U10.5 (GND); also elsewhere on the board
unnamed: C54.1, J6.1, L2.2
unnamed: J7.3, U8.32 (PB3/ADC1)
unnamed: J7.4, U8.31 (PB4/ADC2)
unnamed: J7.5, U8.26 (PB2/ADC3)
unnamed: J7.6, U8.25 (PA10/ADC4)
unnamed: J7.7, U8.3 (PA15/ADC5)
unnamed: C53.1, L2.1, U8.12 (RF)
unnamed: R24.1, U8.5 (UART1_RX/PB7)
unnamed: R26.1, U8.4 (UART1_TX/PB6)
unnamed: R34.1, R38.2, U9.8 (Rs)
unnamed: U16.1 (GND), U16.27 (GND), U16.34 (GND), U16.36 (GND), U16.37 (GND), U16.40 (GND), U16.41 (GND)

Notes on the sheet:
50 Ohm

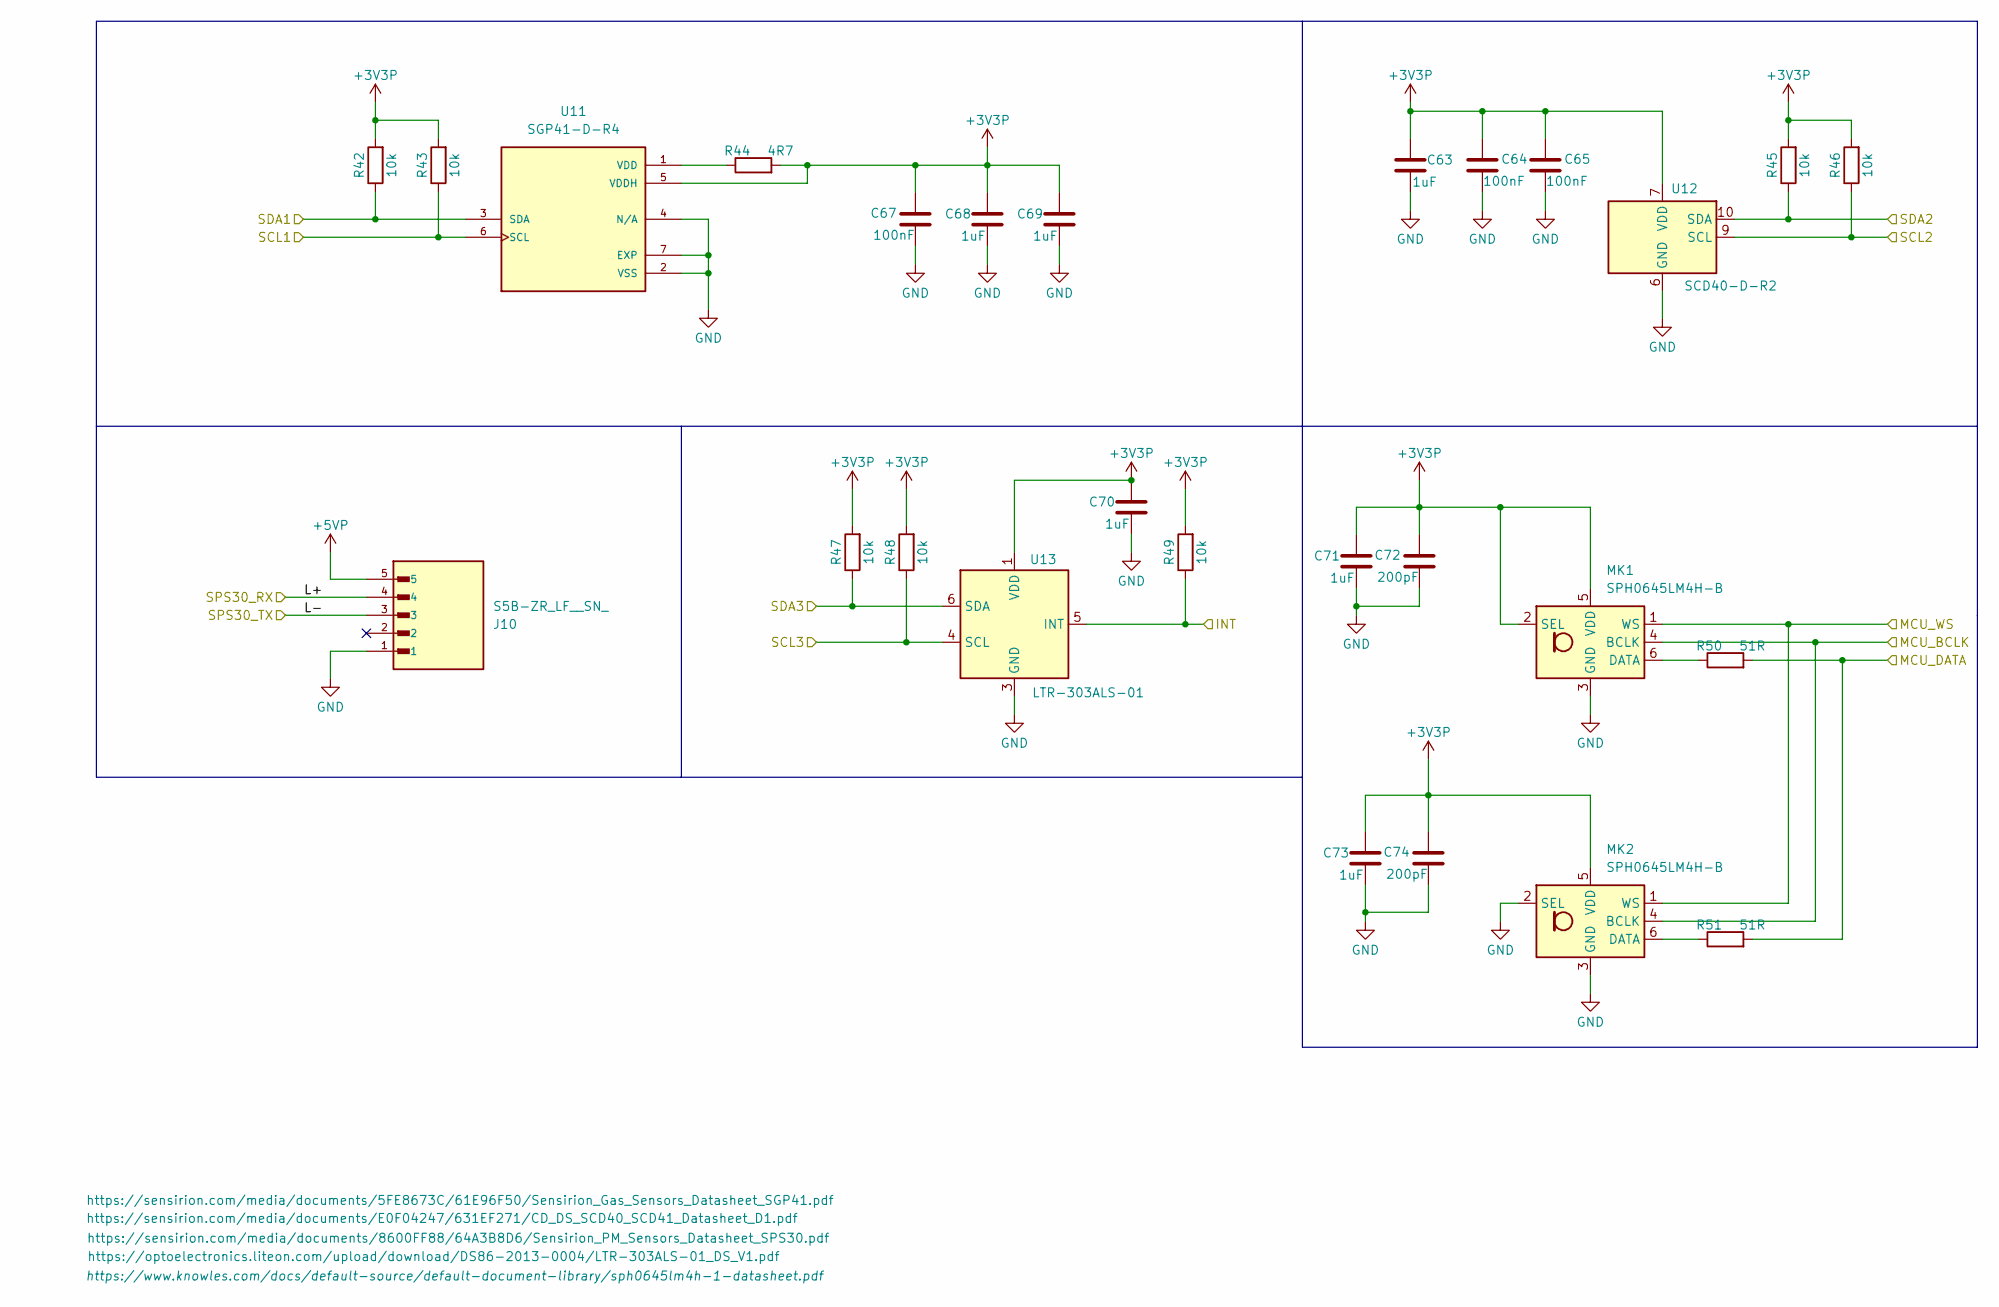
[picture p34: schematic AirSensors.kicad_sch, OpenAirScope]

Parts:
C63, C68, C69, C70, C71, C73: 1uF; C_1206_3216Metric
C64, C65, C67: 100nF; C_0603_1608Metric
C72, C74: 200pF; C_0603_1608Metric
J10: S5B-ZR_LF__SN_; JST_S5B-ZR_LF__SN_
MK1, MK2: SPH0645LM4H-B; Knowles_SPH0645LM4H-6_3.5x2.65mm
R42, R43, R45, R46, R47, R48, R49: 10k; R_0603_1608Metric
R44: 4R7; R_0603_1608Metric
R50, R51: 51R; R_0603_1608Metric
U11: SGP41-D-R4; XDCR_SGP41-D-R4; PARTREV 1.0
U12: SCD40-D-R2; Sensirion_SCD4x-1EP_10.1x10.1mm_P1.25mm_EP4.8x4.8mm
U13: LTR-303ALS-01; Lite-On_LTR-303ALS-01

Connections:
+3V3P: C63.1, C64.2, C65.2, C67.2, C68.1, C69.1, C70.1, C71.1, C72.2, C73.1, C74.2, MK1.2 (SEL), MK1.5 (VDD), MK2.5 (VDD), R42.2, R43.2, R44.2, R45.2, R46.2, R47.2, R48.2, R49.2, U11.5 (VDDH), U12.7 (VDD), U12.19 (VDD), U13.1 (VDD); also elsewhere on the board
+5VP: J10.5; also elsewhere on the board
/MCU/INT: R49.1, U13.5 (INT); also elsewhere on the board
/MCU/MCU_BCLK: MK1.4 (BCLK), MK2.4 (BCLK); also elsewhere on the board
/MCU/MCU_DATA: R50.2, R51.2; also elsewhere on the board
/MCU/MCU_SCL1: R42.1, U11.3 (SDA); also elsewhere on the board
/MCU/MCU_SCL2: R46.1, U12.9 (SCL); also elsewhere on the board
/MCU/MCU_SCL4: R48.1, U13.4 (SCL); also elsewhere on the board
/MCU/MCU_SDA1: R43.1, U11.6 (SCL); also elsewhere on the board
/MCU/MCU_SDA2: R45.1, U12.10 (SDA); also elsewhere on the board
/MCU/MCU_SDA4: R47.1, U13.6 (SDA); also elsewhere on the board
/MCU/MCU_WS: MK1.1 (WS), MK2.1 (WS); also elsewhere on the board
/Sensors/L+: J10.4; also elsewhere on the board
/Sensors/L-: J10.3; also elsewhere on the board
GND: C63.2, C64.1, C65.1, C67.1, C68.2, C69.2, C70.2, C71.2, C72.1, C73.2, C74.1, J10.1, MK1.3 (GND), MK2.2 (SEL), MK2.3 (GND), U11.2 (VSS), U11.4 (N/A), U11.7 (EXP), U12.6 (GND), U12.20 (GND), U12.21 (GND), U13.3 (GND); also elsewhere on the board
unnamed: MK1.6 (DATA), R50.1
unnamed: MK2.6 (DATA), R51.1
unnamed: R44.1, U11.1 (VDD)

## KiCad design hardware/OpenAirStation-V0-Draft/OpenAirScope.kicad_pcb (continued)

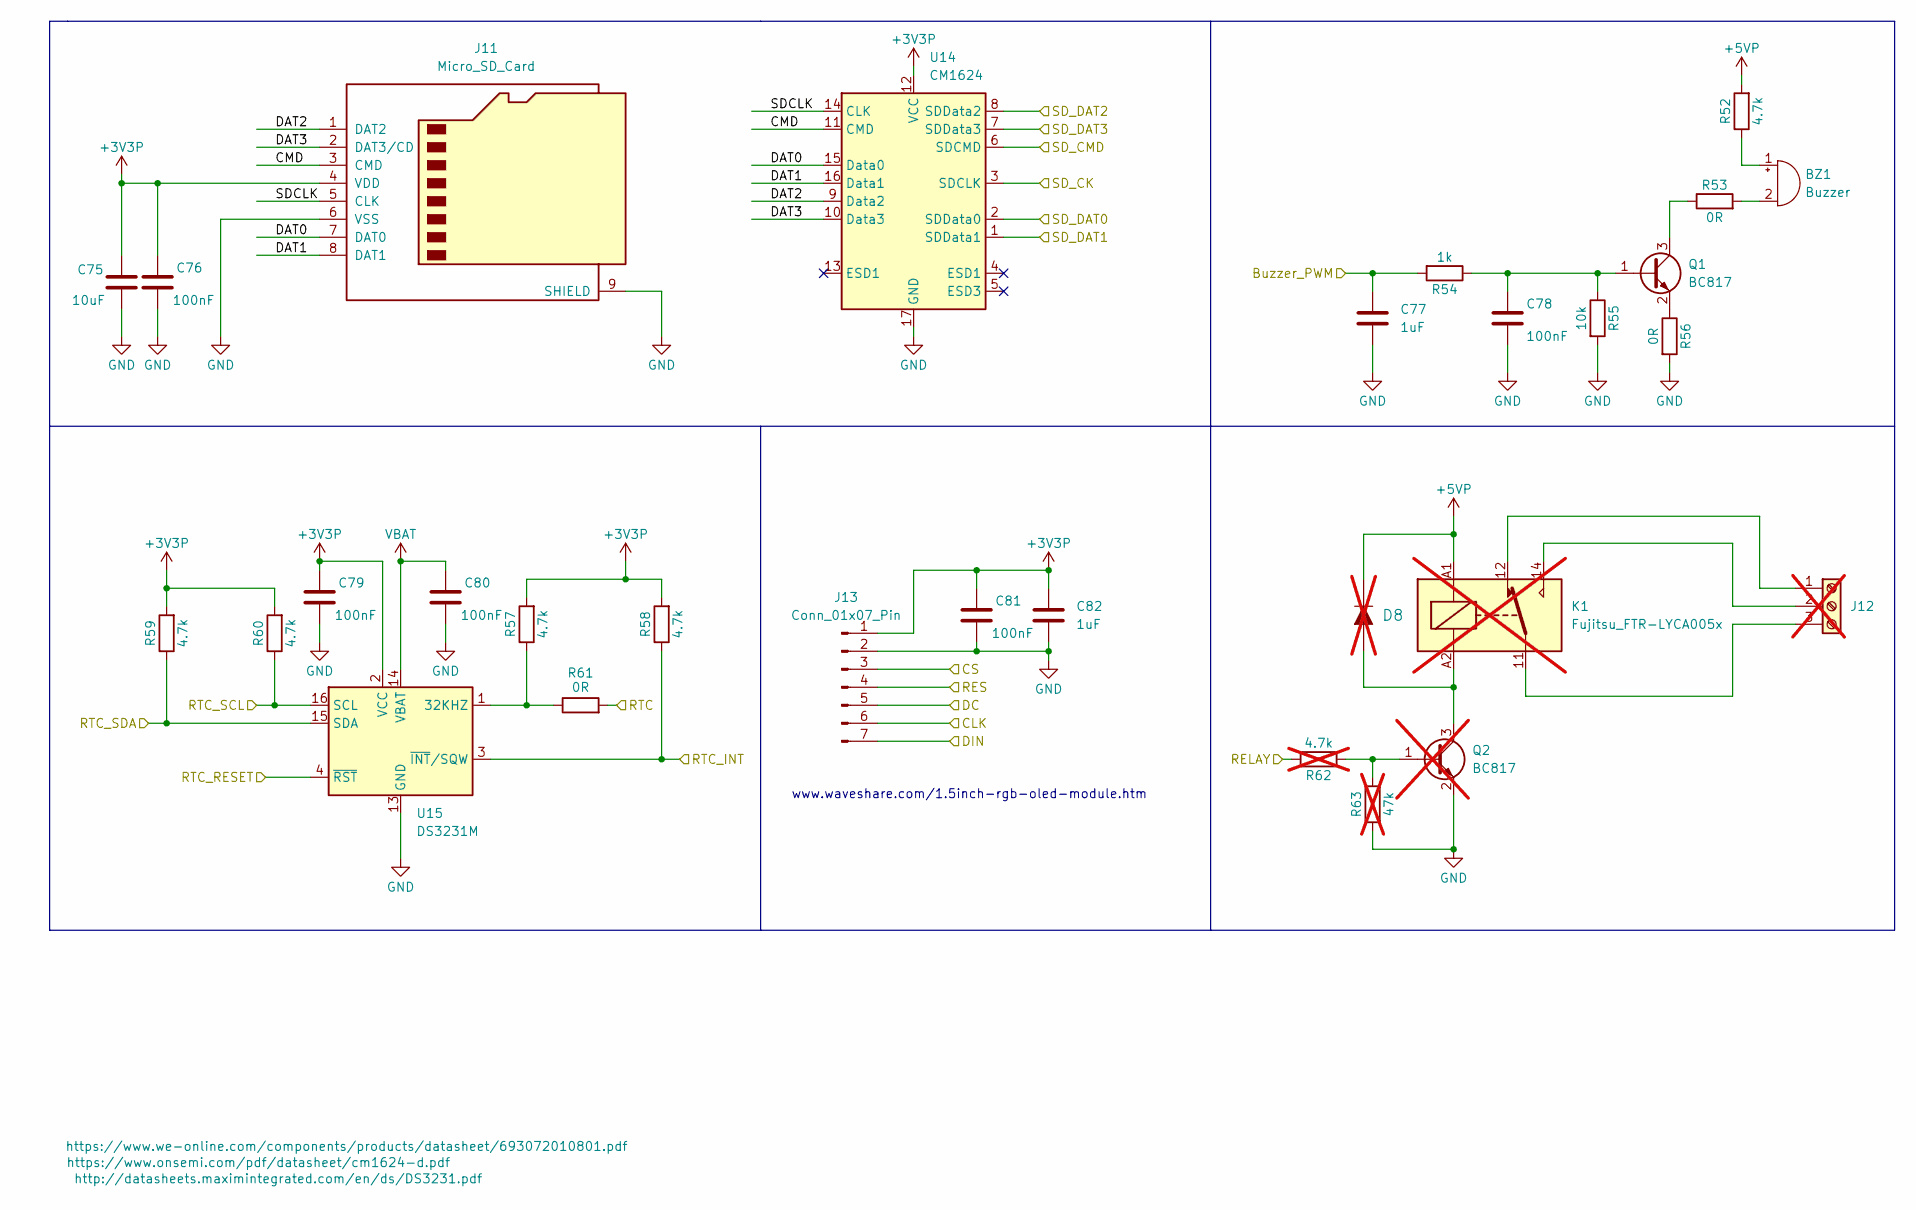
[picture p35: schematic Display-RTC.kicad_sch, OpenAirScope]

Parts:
BZ1: Buzzer; MagneticBuzzer_ProSignal_ABT-410-RC
C75: 10uF; C_0603_1608Metric
C76, C78, C79, C80, C81: 100nF; C_0603_1608Metric
C77, C82: 1uF; C_1206_3216Metric
D8: 1N4148W-TP; SOD-123; MPN 1N4148W-TP; Digi-Key_PN 1N4148WTPMSCT-ND; not fitted
J11: Micro_SD_Card; microSD_HC_Wuerth_693072010801
J12: Screw_Terminal_01x03; TerminalBlock_MetzConnect_Type059_RT06303HBWC_1x03_P3.50mm_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; not fitted
J13: Conn_01x07_Pin; PinHeader_1x07_P2.54mm_Vertical
K1: Fujitsu_FTR-LYCA005x; Relay_SPDT_Fujitsu_FTR-LYCA005x_FormC_Vertical; not fitted
Q1: BC817; SOT-23
Q2: BC817; SOT-23; not fitted
R52, R57, R58, R59, R60: 4.7k; R_0603_1608Metric
R53, R56, R61: 0R; R_0603_1608Metric
R54: 1k; R_0603_1608Metric
R55: 10k; R_0603_1608Metric
R62: 4.7k; R_0603_1608Metric; not fitted
R63: 47k; R_0603_1608Metric; not fitted
U14: CM1624; OnSemi_UDFN-16-1EP_1.35x3.3mm_P0.4mm_EP0.4x2.8mm
U15: DS3231M; SOIC-16W_7.5x10.3mm_P1.27mm

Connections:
+3V3P: C75.1, C76.1, C79.1, C81.1, C82.1, J11.4 (VDD), J13.1, R57.2, R58.2, R59.2, R60.2, U14.12 (VCC), U15.2 (VCC); also elsewhere on the board
+5VP: D8.K, K1.A1, R52.2; also elsewhere on the board
/Display-RTC/Buzzer_PWM: C77.1, R54.2; also elsewhere on the board
/Display-RTC/CLK: J13.6; also elsewhere on the board
/Display-RTC/CMD: J11.3 (CMD), U14.11 (CMD)
/Display-RTC/CS: J13.3; also elsewhere on the board
/Display-RTC/DAT0: J11.7 (DAT0), U14.15 (Data0)
/Display-RTC/DAT1: J11.8 (DAT1), U14.16 (Data1)
/Display-RTC/DAT2: J11.1 (DAT2), U14.9 (Data2)
/Display-RTC/DAT3: J11.2 (DAT3/CD), U14.10 (Data3)
/Display-RTC/DC: J13.5; also elsewhere on the board
/Display-RTC/DIN: J13.7; also elsewhere on the board
/Display-RTC/RES: J13.4; also elsewhere on the board
/Display-RTC/RTC: R61.2; also elsewhere on the board
/Display-RTC/RTC_INT: R58.1, U15.3 (~INT/SQW); also elsewhere on the board
/Display-RTC/RTC_RESET: U15.4 (~RST); also elsewhere on the board
/Display-RTC/RTC_SCL: R60.1, U15.16 (SCL); also elsewhere on the board
/Display-RTC/RTC_SDA: R59.1, U15.15 (SDA); also elsewhere on the board
/Display-RTC/SDCLK: J11.5 (CLK), U14.14 (CLK)
/Display-RTC/SD_CK: U14.3 (SDCLK); also elsewhere on the board
/Display-RTC/SD_CMD: U14.6 (SDCMD); also elsewhere on the board
/Display-RTC/SD_DAT0: U14.2 (SDData0); also elsewhere on the board
/Display-RTC/SD_DAT1: U14.1 (SDData1); also elsewhere on the board
/Display-RTC/SD_DAT2: U14.8 (SDData2); also elsewhere on the board
/Display-RTC/SD_DAT3: U14.7 (SDData3); also elsewhere on the board
GND: C75.2, C76.2, C77.2, C78.2, C79.2, C80.2, C81.2, C82.2, J11.6 (VSS), J11.9 (SHIELD), J13.2, Q2.2 (E), R55.2, R56.2, R63.1, U14.17 (GND), U15.5 (GND), U15.6 (GND), U15.7 (GND), U15.8 (GND), U15.9 (GND), U15.10 (GND), U15.11 (GND), U15.12 (GND), U15.13 (GND); also elsewhere on the board
unnamed: BZ1.1 (+), R52.1
unnamed: BZ1.2 (-), R53.2
unnamed: D8.A, K1.A2, Q2.3 (C)
unnamed: J12.1, K1.12
unnamed: J12.2, K1.14
unnamed: J12.3, K1.11
unnamed: C78.1, Q1.1 (B), R54.1, R55.1
unnamed: Q1.3 (C), R53.1
unnamed: Q1.2 (E), R56.1
unnamed: Q2.1 (B), R62.1, R63.2
unnamed: R57.1, R61.1, U15.1 (32KHZ)
VBAT: C80.1, U15.14 (VBAT); also elsewhere on the board

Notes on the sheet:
www.waveshare.com/1.5inch-rgb-oled-module.htm

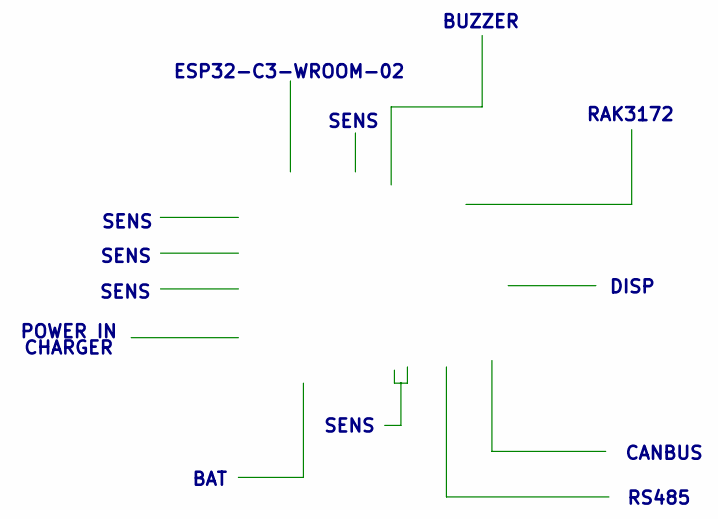
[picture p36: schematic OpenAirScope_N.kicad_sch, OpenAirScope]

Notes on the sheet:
CHARGER
DISP
SENS
BAT
ESP32-C3-WROOM-02
RAK3172
RS485
CANBUS
POWER IN
BUZZER

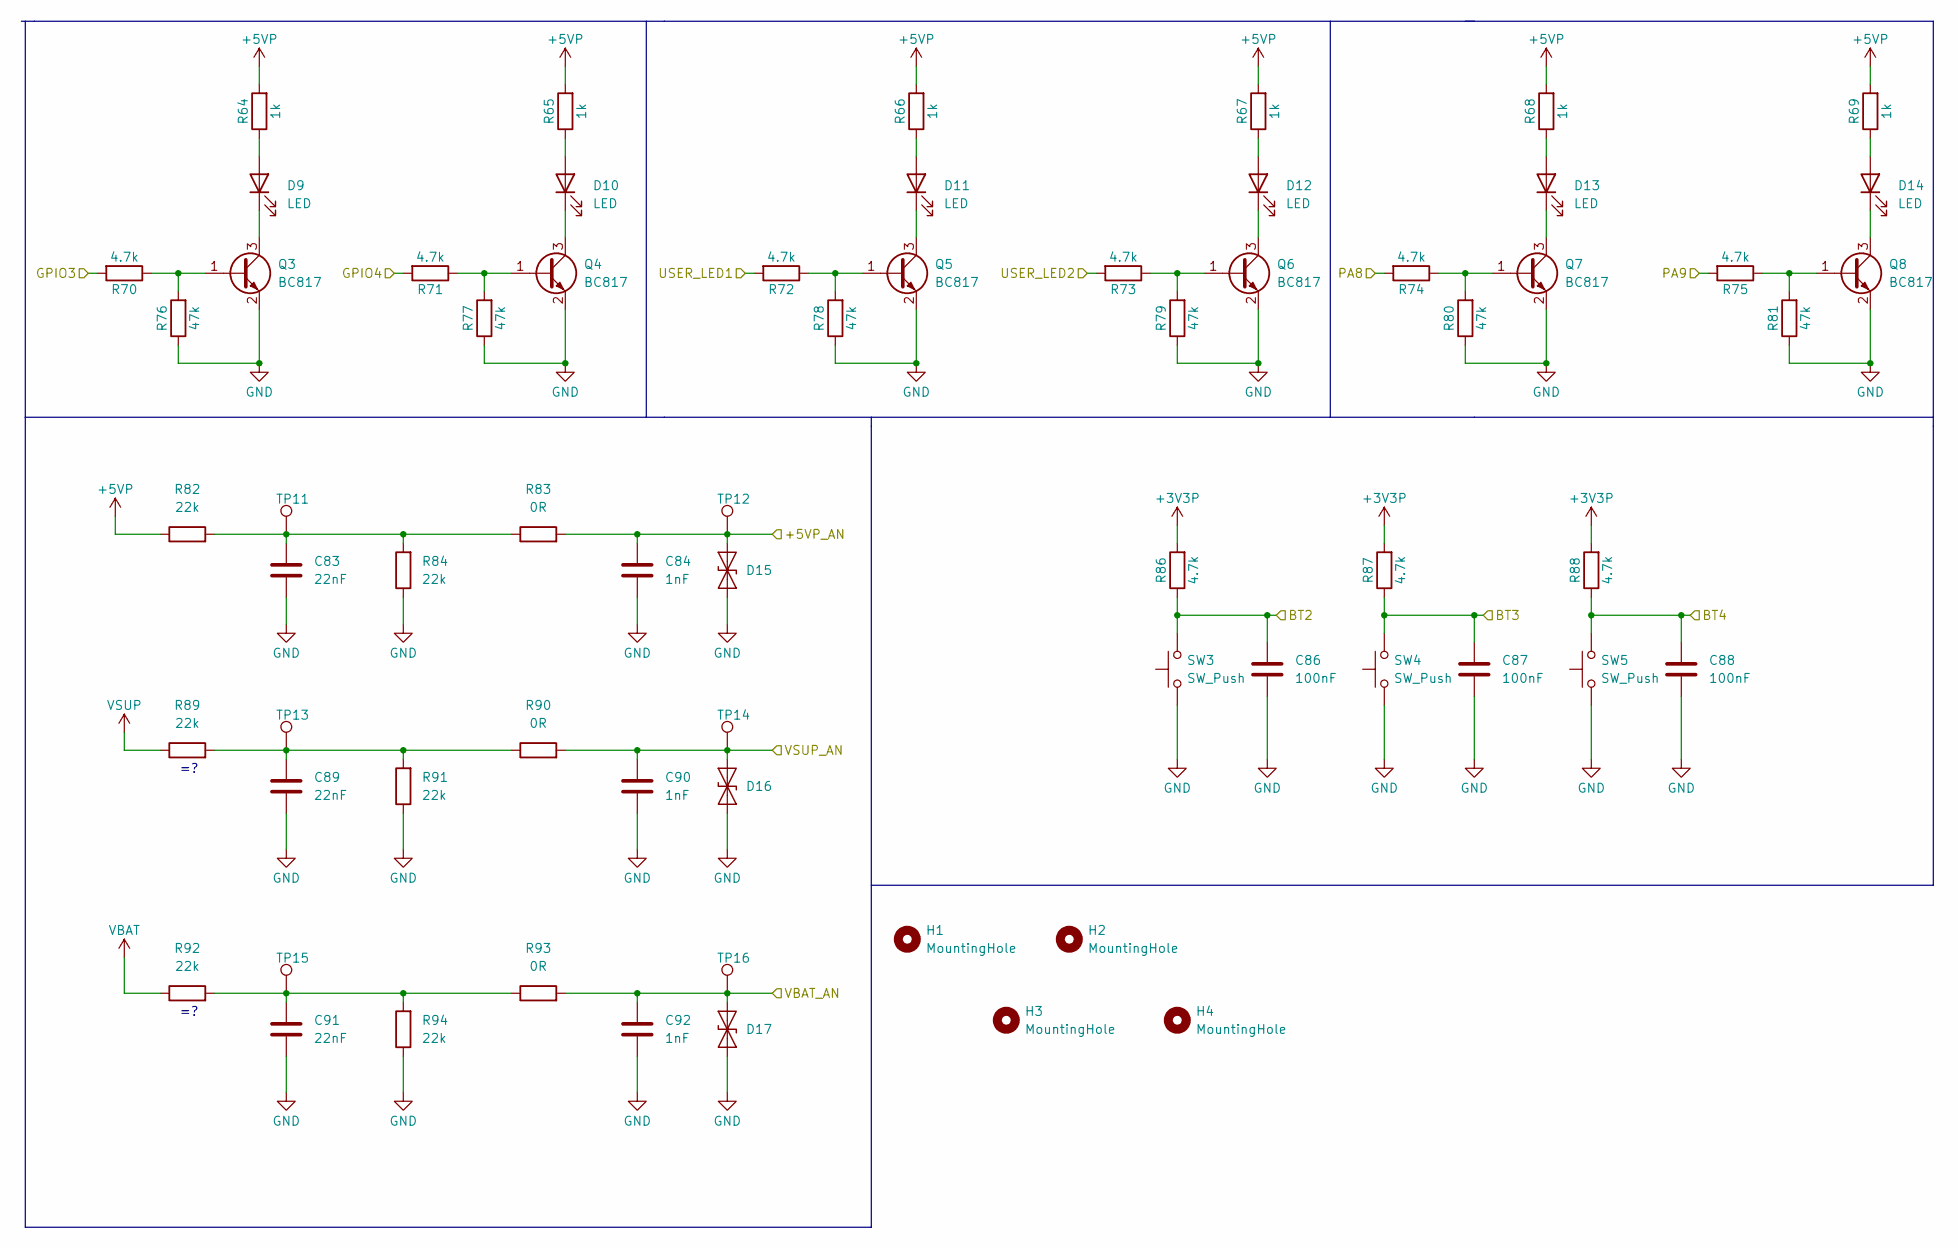
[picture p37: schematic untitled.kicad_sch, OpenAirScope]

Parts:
C83, C89, C91: 22nF; C_0603_1608Metric
C84, C90, C92: 1nF; C_0603_1608Metric
C86, C87, C88: 100nF; C_0603_1608Metric
D9, D10, D11, D12, D13, D14: LED; LED_0603_1608Metric
D15, D16, D17: ESD9B3.3ST5G; D_SOD-923
H1, H2, H3, H4: MountingHole; MountingHole_3.2mm_M3_ISO7380
Q3, Q4, Q5, Q6, Q7, Q8: BC817; SOT-23
R64, R65, R66, R67, R68, R69: 1k; R_0603_1608Metric
R70, R71, R72, R73, R74, R75, R86, R87, R88: 4.7k; R_0603_1608Metric
R76, R77, R78, R79, R80, R81: 47k; R_0603_1608Metric
R82, R84, R89, R91, R92, R94: 22k; R_0603_1608Metric
R83, R90, R93: 0R; R_0603_1608Metric
SW3, SW4, SW5: SW_Push; SW_PUSH_6mm_H13mm
TP11, TP12, TP13, TP14, TP15, TP16: TestPoint; TestPoint_Pad_D1.0mm

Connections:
+3V3P: R86.2, R87.2, R88.2; also elsewhere on the board
+5VP: R64.2, R65.2, R66.2, R67.2, R68.2, R69.2, R82.1; also elsewhere on the board
/Conn/GPIO3: R70.2; also elsewhere on the board
/Conn/GPIO4: R71.2; also elsewhere on the board
/Conn/PA8: R74.2; also elsewhere on the board
/Conn/PA9: R75.2; also elsewhere on the board
/Indicators/+5VP_AN: C84.1, D15.2 (A2), R83.2, TP12.1; also elsewhere on the board
/Indicators/BT2: C86.1, R86.1, SW3.2; also elsewhere on the board
/Indicators/BT3: C87.1, R87.1, SW4.2; also elsewhere on the board
/Indicators/BT4: C88.1, R88.1, SW5.2; also elsewhere on the board
/Indicators/USER_LED1: R72.2; also elsewhere on the board
/Indicators/USER_LED2: R73.2; also elsewhere on the board
/Indicators/VBAT_AN: C92.1, D17.2 (A2), R93.2, TP16.1; also elsewhere on the board
/Indicators/VSUP_AN: C90.1, D16.2 (A2), R90.2, TP14.1; also elsewhere on the board
GND: C83.2, C84.2, C86.2, C87.2, C88.2, C89.2, C90.2, C91.2, C92.2, D15.1 (A1), D16.1 (A1), D17.1 (A1), Q3.2 (E), Q4.2 (E), Q5.2 (E), Q6.2 (E), Q7.2 (E), Q8.2 (E), R76.1, R77.1, R78.1, R79.1, R80.1, R81.1, R84.1, R91.1, R94.1, SW3.1, SW4.1, SW5.1; also elsewhere on the board
unnamed: C83.1, R82.2, R83.1, R84.2, TP11.1
unnamed: C89.1, R89.2, R90.1, R91.2, TP13.1
unnamed: C91.1, R92.2, R93.1, R94.2, TP15.1
unnamed: D9.2 (A), R64.1
unnamed: D9.1 (K), Q3.3 (C)
unnamed: D10.2 (A), R65.1
unnamed: D10.1 (K), Q4.3 (C)
unnamed: D11.2 (A), R66.1
unnamed: D11.1 (K), Q5.3 (C)
unnamed: D12.2 (A), R67.1
unnamed: D12.1 (K), Q6.3 (C)
unnamed: D13.2 (A), R68.1
unnamed: D13.1 (K), Q7.3 (C)
unnamed: D14.2 (A), R69.1
unnamed: D14.1 (K), Q8.3 (C)
unnamed: Q3.1 (B), R70.1, R76.2
unnamed: Q4.1 (B), R71.1, R77.2
unnamed: Q5.1 (B), R72.1, R78.2
unnamed: Q6.1 (B), R73.1, R79.2
unnamed: Q7.1 (B), R74.1, R80.2
unnamed: Q8.1 (B), R75.1, R81.2
VBAT: R92.1; also elsewhere on the board
VSUP: R89.1; also elsewhere on the board

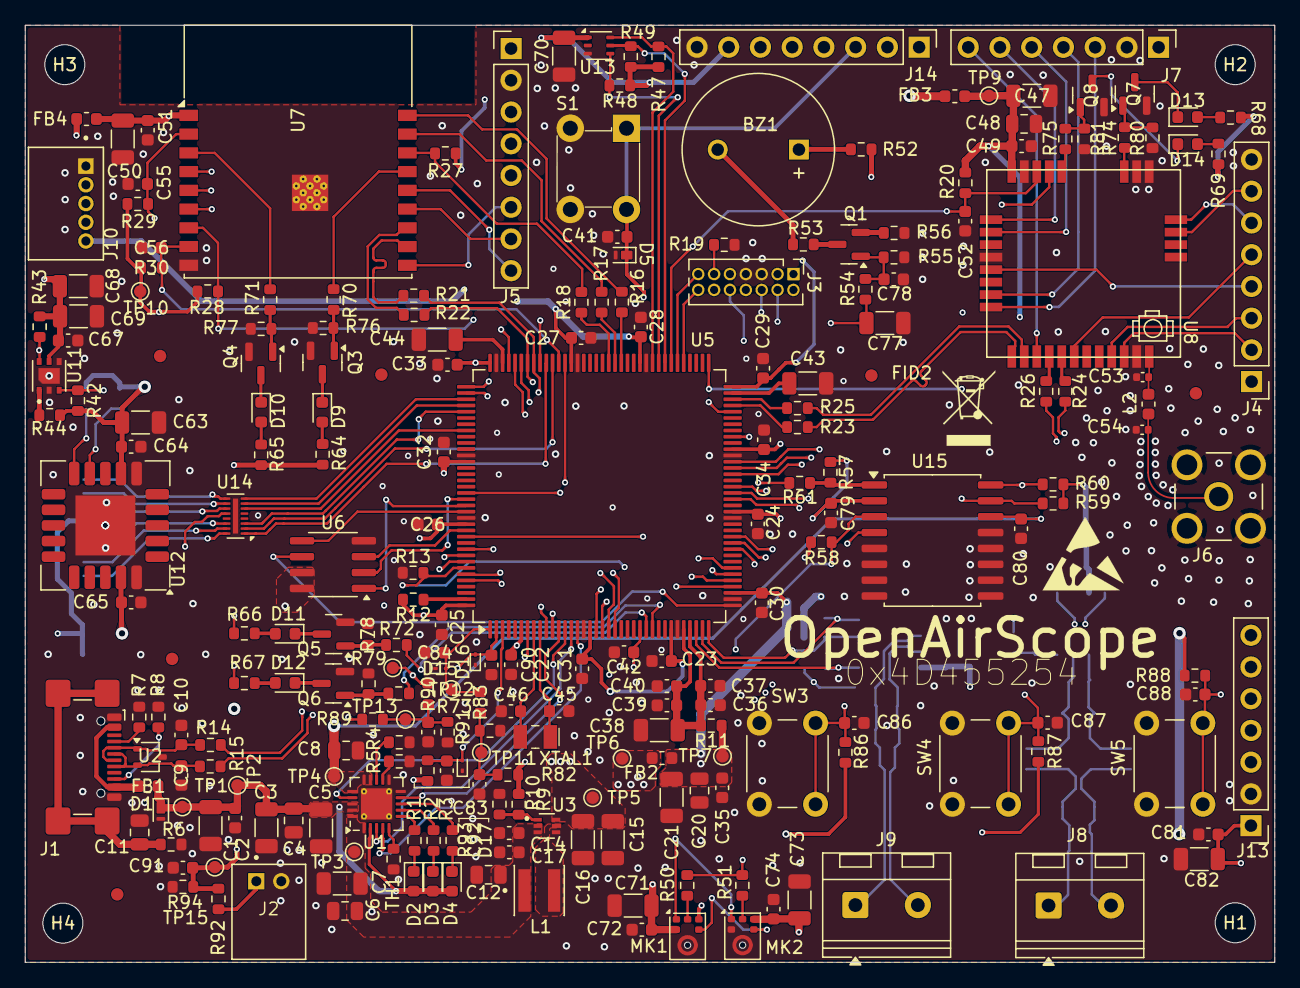
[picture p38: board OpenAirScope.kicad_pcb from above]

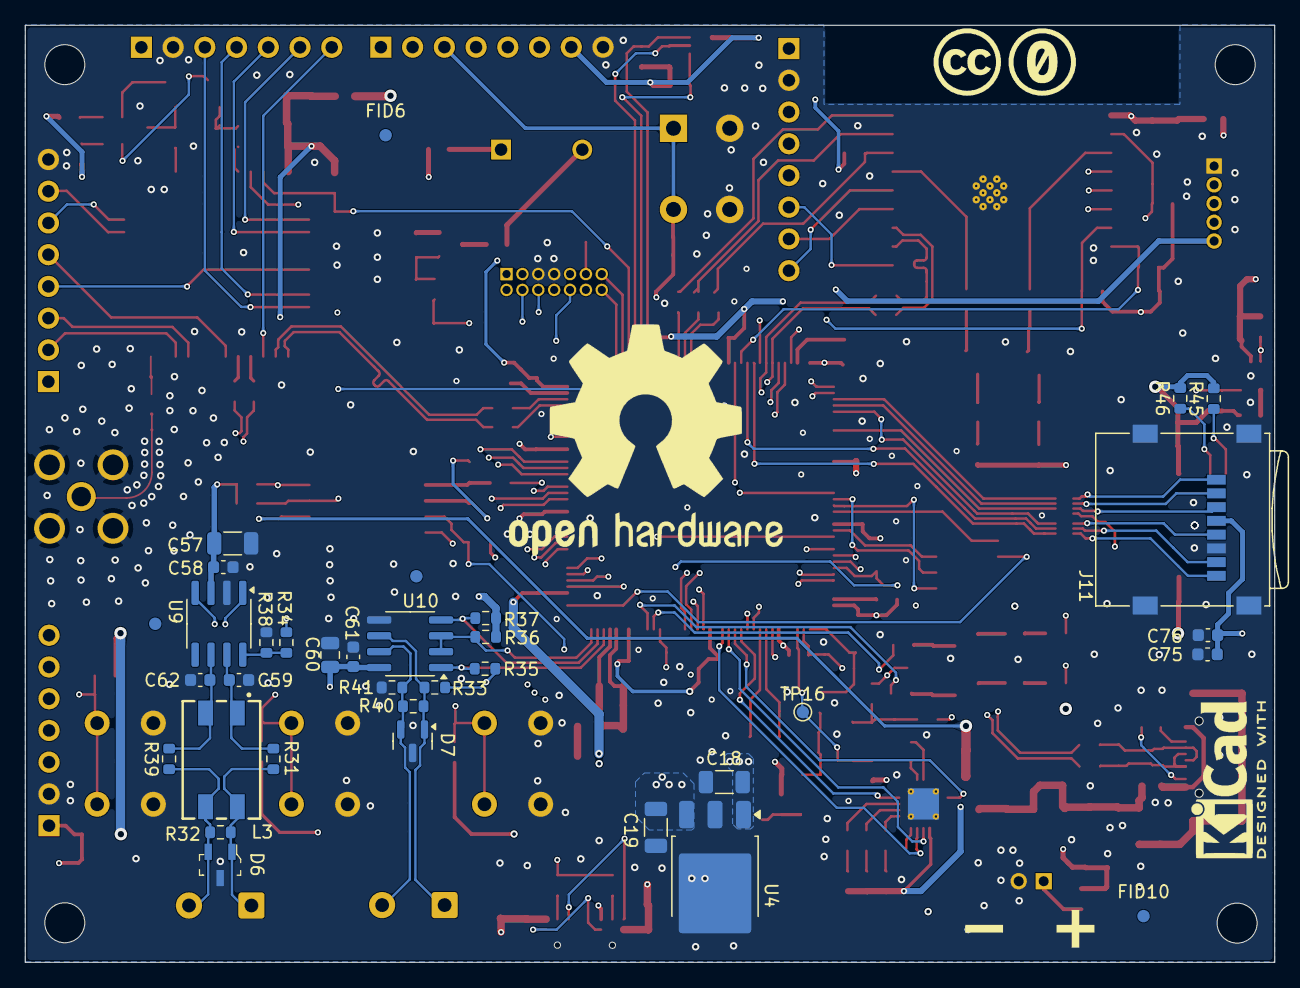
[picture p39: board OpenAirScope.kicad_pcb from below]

Board: 4 copper layers, 100.0 x 75.0 mm, 281 parts (38 on the bottom side), 184 nets.

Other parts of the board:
FID1, FID2, FID3, FID4, FID5, FID6, FID7, FID8, FID9, FID10: Fiducial; Fiducial_1mm_Mask2mm
l1: ESD-Logo_6.6x6mm_SilkScreen
l2: WEEE-Logo_4.2x6mm_SilkScreen
l3: OSHW-Logo2_24.3x20mm_SilkScreen
l4: KiCad-Logo2_5mm_SilkScreen
l5: Symbol_CreativeCommonsPublicDomain_SilkScreenTop_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; Symbol_CreativeCommonsPublicDomain_SilkScreenTop_Small

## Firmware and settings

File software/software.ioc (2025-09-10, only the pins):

Mcu.UserName=STM32H743ZITx
PA0.Signal=UART4_TX
PA1.Signal=UART4_RX
PA10.Signal=USART1_RX
PA11.Signal=USB_OTG_FS_DM
PA12.Signal=USB_OTG_FS_DP
PA2.Signal=GPIO_Output
PA3.Signal=GPIO_Output
PA7.Signal=GPIO_Output
PA8.Signal=GPIO_Output
PA9.Signal=USART1_TX
PB0.Signal=GPIO_Output
PB1.Signal=GPIO_Output
PB10.Signal=USART3_TX
PB11.Signal=USART3_RX
PB12.Signal=GPIO_Output
PB2.Signal=GPIO_Output
PB5.Signal=SPI1_MOSI
PB6.Signal=I2C1_SCL
PB7.Signal=I2C1_SDA
PB8.Signal=FDCAN1_RX
PB9.Signal=FDCAN1_TX
PC0.Signal=GPIO_Output
PC1.Signal=GPIO_Output
PC10.Signal=SDMMC1_D2
PC11.Signal=SDMMC1_D3
PC12.Signal=SDMMC1_CK
PC13.Signal=RTC_OUT_ALARM
PC6.Signal=S_TIM3_CH1
PC7.Signal=GPIO_Output
PC8.Signal=SDMMC1_D0
PC9.Signal=SDMMC1_D1
PD10.Signal=GPIO_Output
PD11.Signal=GPIO_Input
PD12.Signal=I2C4_SCL
PD13.Signal=I2C4_SDA
PD2.Signal=SDMMC1_CMD
PE11.Signal=S_TIM1_CH2
PE15.Signal=GPIO_Output
PE2.Signal=GPIO_Analog
PE3.Signal=GPIO_Analog
PE4.Signal=GPIO_Analog
PE7.Signal=GPIO_Input
PE8.Signal=GPIO_Input
PE9.Signal=GPIO_Input
PF0.Signal=I2C2_SDA
PF1.Signal=I2C2_SCL
PF2.Signal=GPIO_Output
PF3.Signal=GPIO_Output
PF4.Signal=GPIO_Output
PF5.Signal=GPIO_Output
PF6.Signal=UART7_RX
PF7.Signal=UART7_TX
PF8.Signal=GPIO_Input
PF9.Signal=GPIO_Input
PG0.Signal=GPIO_Output
PG1.Signal=GPIO_Input
PG11.Signal=SPI1_SCK
PG12.Signal=SPI6_MISO
PG13.Signal=SPI6_SCK
PG14.Signal=SPI6_MOSI
PG15.Signal=GPIO_Output
PG2.Signal=GPIO_Analog
PG3.Signal=GPIO_Output
PG4.Signal=GPIO_Output

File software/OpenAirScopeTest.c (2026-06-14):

/**
 ******************************************************************************
 * @file    OpenAirScopeTest.c
 * @brief   OpenAirScope Hardware Test Framework - Implementation
 *
 * @details For every peripheral this module provides:
 *          - Full peripheral init (global handle, error checking enforced)
 *          - PASS / FAIL decision with error-code reporting
 *          - Execution time measurement via HAL_GetTick()
 *          - Result summary printed as an ASCII table over UART4
 *
 * @board   OpenAirScope v1.x  (STM32H743VIT6)
 ******************************************************************************
 */

/* Includes ------------------------------------------------------------------*/
#include "OpenAirScopeTest.h"

/* -------------------------------------------------------------------------
 * Peripheral Handle Definitions
 * -------------------------------------------------------------------------*/
UART_HandleTypeDef  huart4;   /* Debug / log UART  — PA0=TX, PA1=RX        */
UART_HandleTypeDef  huart3;   /* USART3 loopback   — PB10=TX, PB11=RX      */
ADC_HandleTypeDef   hadc1;    /* ADC1                                       */
DAC_HandleTypeDef   hdac1;    /* DAC1                                       */
I2C_HandleTypeDef   hi2c1;    /* I2C1  — PB6=SCL, PB7=SDA                  */
SPI_HandleTypeDef   hspi1;    /* SPI1  — PG11=SCK, PB5=MOSI                */
/* hfdcan1: defined in main.c, used here via extern                         */

/* -------------------------------------------------------------------------
 * Module-private Variables
 * -------------------------------------------------------------------------*/
#define MAX_TESTS   8U

static TestRecord_t  s_records[MAX_TESTS];
static uint8_t       s_testCount = 0U;
static TestSummary_t s_summary   = {0};

/* -------------------------------------------------------------------------
 * Helper Utilities
 * -------------------------------------------------------------------------*/

/** Redirect printf output to UART4 (newlib retarget) */
int __io_putchar(int ch)
{
    HAL_UART_Transmit(&huart4, (uint8_t *)&ch, 1U, HAL_MAX_DELAY);
    return ch;
}

/**
 * @brief  Prints a separator line of a given character and length.
 */
static void print_separator(char c, uint8_t len)
{
    for (uint8_t i = 0U; i < len; i++) {
        __io_putchar(c);
    }
    printf("\r\n");
}

/**
 * @brief  Initialises a test record and returns the start tick.
 */
static uint32_t record_start(TestRecord_t *rec, const char *name)
{
    memset(rec, 0, sizeof(TestRecord_t));
    rec->name   = name;
    rec->result = TEST_RESULT_PENDING;
    return HAL_GetTick();
}

/**
 * @brief  Finalises a test record with its result and elapsed time.
 */
static void record_finish(TestRecord_t *rec, uint32_t startTick,
                           TestResult_t result, const char *detail)
{
    rec->result     = result;
    rec->durationMs = HAL_GetTick() - startTick;
    if (detail != NULL) {
        strncpy(rec->detail, detail, sizeof(rec->detail) - 1U);
    }
}

/**
 * @brief  Prints a single test record as a formatted table row.
 */
static void print_record(const TestRecord_t *rec)
{
    const char *resultStr;
    switch (rec->result) {
        case TEST_RESULT_PASS: resultStr = "PASS"; break;
        case TEST_RESULT_FAIL: resultStr = "FAIL"; break;
        case TEST_RESULT_SKIP: resultStr = "SKIP"; break;
        default:               resultStr = "????"; break;
    }
    printf("| %-10s | %-4s | %5lu ms | %-40s |\r\n",
           rec->name, resultStr, rec->durationMs, rec->detail);
}

/* =========================================================================
 * UART4 Peripheral Init (Debug Port)
 * =========================================================================*/
static HAL_StatusTypeDef uart4_init(void)
{
    GPIO_InitTypeDef gpio = {0};

    /* Enable GPIO and UART4 peripheral clocks */
    __HAL_RCC_GPIOA_CLK_ENABLE();
    __HAL_RCC_UART4_CLK_ENABLE();

    /* PA0 = UART4_TX, PA1 = UART4_RX */
    gpio.Pin       = TEST_UART_TX_PIN | TEST_UART_RX_PIN;
    gpio.Mode      = GPIO_MODE_AF_PP;
    gpio.Pull      = GPIO_PULLUP;
    gpio.Speed     = GPIO_SPEED_FREQ_LOW;
    gpio.Alternate = TEST_UART_AF;
    HAL_GPIO_Init(TEST_UART_TX_PORT, &gpio);

    huart4.Instance          = TEST_UART_INSTANCE;
    huart4.Init.BaudRate     = TEST_UART_BAUDRATE;
    huart4.Init.WordLength   = UART_WORDLENGTH_8B;
    huart4.Init.StopBits     = UART_STOPBITS_1;
    huart4.Init.Parity       = UART_PARITY_NONE;
    huart4.Init.Mode         = UART_MODE_TX_RX;
    huart4.Init.HwFlowCtl    = UART_HWCONTROL_NONE;
    huart4.Init.OverSampling = UART_OVERSAMPLING_16;

    return HAL_UART_Init(&huart4);
}

/* =========================================================================
 * PUBLIC: OpenAirScopeTest_Init
 * =========================================================================*/
HAL_StatusTypeDef OpenAirScopeTest_Init(void)
{
    HAL_StatusTypeDef status = uart4_init();
    if (status != HAL_OK) {
        /* Debug port could not be opened — signal failure via LED blink */
        HAL_GPIO_WritePin(TEST_LED_PORT, TEST_LED_PIN, GPIO_PIN_SET);
        HAL_Delay(2000U);
        HAL_GPIO_WritePin(TEST_LED_PORT, TEST_LED_PIN, GPIO_PIN_RESET);
        return HAL_ERROR;
    }

    /* Print banner */
    printf("\r\n");
    print_separator('=', 70);
    printf("  OpenAirScope Hardware Test Framework\r\n");
    printf("  Board : STM32H743VIT6\r\n");
    printf("  Build : %s  %s\r\n", __DATE__, __TIME__);
    print_separator('=', 70);
    printf("\r\n");

    s_testCount = 0U;
    memset(&s_summary, 0, sizeof(s_summary));

    return HAL_OK;
}
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
